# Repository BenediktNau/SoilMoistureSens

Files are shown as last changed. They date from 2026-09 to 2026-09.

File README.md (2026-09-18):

# SoilMoistureSens

Batteriebetriebener Bodenfeuchtesensor auf NodeMCU (ESP8266) mit Solarladung.
Misst alle 15 Minuten, sendet per MQTT und schläft dazwischen im Deep Sleep.
Einstellungen laufen über eine Web-Oberfläche auf dem Chip.

## Hardware

- NodeMCU (ESP-12E), versorgt über den **3V3-Pin**, VIN bleibt frei
- ADS1115 am I2C: SDA GPIO4 (D2), SCL GPIO5 (D1), ADDR an GND (Adresse 0x48),
  Sensorausgang an A0 des ADS1115. Der interne A0 des ESP bleibt frei.
- Kapazitiver Feuchtesensor v1.2 an **5 V**. Auf vielen dieser Sensoren sitzt
  ein NE555, der an 3,3 V kaum zwischen nass und trocken unterscheidet. Die
  5 V kommen aus einem MT3608-Step-up, der direkt am Akku hängt, nicht an den
  geregelten 3,3 V.
- Sensorversorgung geschaltet: GPIO14 (D5) treibt das Gate eines
  Logic-Level-N-MOSFET (z. B. 2N7000, besser IRLML2502), 10 kΩ vom Gate nach
  GND. Im Drain liegen die Masse des Sensors **und** die Masse des MT3608.
  Ein Step-up reicht auch im Ruhezustand die Eingangsspannung durch, darum
  wird er mit abgeschaltet.
- 6-V-Solarpanel 14,5 cm, davor ein Step-down auf 5,0 V (MP1584 oder
  LM2596), dann das HW-775-Lademodul (IP5306, VIN verträgt nur 4,75 bis
  5,5 V). 18650-Akku **mit Schutzschaltung** (protected, das BAT-Pad hängt
  ungeschützt an der Zelle).
- HT7333 vom BAT-Pad auf den 3V3-Pin, je 10 µF an Ein- und Ausgang. VOUT des
  HW-775 bleibt frei, der 5-V-Ausgang schaltet im Deep Sleep nach 32 s ab.
- **Brücke D0 (GPIO16) an RST**: ohne sie wacht der Chip nicht aus dem Deep Sleep auf
- Kein zusätzlicher Taster: der Reset-Taster des NodeMCU, zweimal innerhalb
  von 3 s gedrückt, öffnet den Konfigmodus
- Gehäuse unter `case/`

### Schaltplan

Rev D, Stand 2026-09-18. Quelle mit Verdrahtungstabellen und Hinweisen:
[`docs/hardware/schaltplan.html`](docs/hardware/schaltplan.html).

**Blatt 1, Versorgung**

Schaltplan Versorgung: Panel, Step-down, HW-775, 18650, HT7333, NodeMCU

**Blatt 2, Messpfad**

Schaltplan Messpfad: NodeMCU, ADS1115, MT3608, Sensor, MOSFET

Vor dem ersten Einschalten: Step-down ohne Last auf 5,0 V einstellen,
MT3608 ohne Sensor auf 5,0 V einstellen (der Trimmer reagiert oft erst nach
15 bis 25 Umdrehungen), HT7333-Ausgang auf 3,3 V prüfen. Den Sensorausgang
einmal in trockener Luft messen: der ADS1115 verträgt an 3,3 V Versorgung
höchstens 3,6 V am Eingang, typisch liefert der Sensor bis 3,0 V.

### Stückliste

| Ref | Teil | Typ / Wert | Hinweis |
|---|---|---|---|
| PV1 | Solarpanel | 6 V, 14,5 cm | Leerlauf bis 7 V |
| U2 | Step-down-Modul | MP1584EN, alternativ LM2596 | auf 5,0 V eingestellt |
| U1 | Lademodul HW-775 | IP5306 | nur VIN, GND und BAT benutzt |
| BT1 | 18650 Li-Ion mit Halter | protected, 3,0 bis 4,2 V | etwa 3 mm länger als eine nackte Zelle |
| U3 | LDO HT7333-A | 3,3 V, 250 mA | TO-92 von vorn: GND, VIN, VOUT |
| C2, C3 | Kondensator | 10 µF | C3 gern größer, bis 100 µF |
| A1 | NodeMCU | ESP-12E (ESP8266) | Versorgung über den 3V3-Pin |
| U4 | ADS1115-Modul | 16 Bit, I2C 0x48 | ADDR an GND |
| C1 | Kondensator | 100 nF | direkt am ADS1115 |
| U5 | Step-up-Modul MT3608 | auf 5,0 V eingestellt | versorgt nur den Sensor |
| J1 | Bodenfeuchtesensor | kapazitiv v1.2 | mit NE555, braucht 5 V |
| Q1 | N-MOSFET, Logic Level | 2N7000, besser IRLML2502 | schaltet Masse von U5 und J1 |
| R1 | Widerstand | 10 kΩ | Gate von Q1 nach GND |
| JP1 | Drahtbrücke | D0 nach RST | zum Flashen abziehen |

## Flashen

```bash
pio run -e esp12e -t upload
pio device monitor
```

Startet der Upload nicht, die Brücke GPIO16 zu RST für den Upload trennen.

## Bedienung

**Konfigmodus** startet beim ersten Einschalten (ohne Konfiguration) oder nach
zweimaligem Druck auf den Reset-Taster innerhalb von 3 s. Ein einzelner Druck
löst nur einen normalen Messzyklus aus.

1. Mit WLAN `SoilMoisture-Setup` verbinden, Passwort `bodenfeuchte`.
2. `http://192.168.4.1/` öffnen.
3. WLAN, MQTT-Broker, Kalibrierung und Intervall eintragen.
4. "Speichern und Messbetrieb starten".

Sobald das Heimnetz eingetragen ist, ist die Seite auch über die dort
vergebene IP erreichbar (steht im seriellen Monitor und in der WLAN-Karte).

Kalibrieren: Sensor an der Luft halten und bei "trocken" den aktuellen Wert
übernehmen, dann ins Wasserglas und bei "nass" übernehmen. Die Rohwerte des
ADS1115 liegen bei etwa 9600 bis 24000 (0,125 mV pro Schritt). Rohwert -1
heißt: der ADS1115 antwortet nicht, dann Verdrahtung und Adresse prüfen.

Statische IP: Wer eine feste Adresse einträgt, spart beim Aufwachen die
DHCP-Zeit. Gateway und Subnetzmaske sind dann Pflicht, DNS ist optional
(leer = Gateway). Feld leer lassen bedeutet DHCP.

Der Konfigmodus endet nach 5 Minuten ohne Bedienung von selbst.

**Messbetrieb**: aufwachen, Sensor und Step-up einschalten, messen, beides aus, senden,
schlafen. Ziel unter 10 Sekunden wach. Ohne WLAN oder Broker schläft der Sensor trotzdem bis zum nächsten
Intervall, damit der Akku geschont wird.

## MQTT

Topic `<Präfix>/<Gerätename>/state`, retained:

```json
{"raw":16500,"percent":52,"level":"ok","rssi":-61}
```

`level` ist `dry`, `ok` oder `wet` nach den eingestellten Schwellen.

## Entwicklung

```bash
pio test -e native      # Logik-Tests auf dem PC (braucht g++)
pio run -e esp12e       # Firmware bauen
```

Konfiguration liegt in `/config.json` im LittleFS des Chips. Zum Zurücksetzen
`pio run -e esp12e -t erase` und neu flashen.

Design-Spec: `docs/superpowers/specs/2026-09-12-config-ui-and-sleep-mode-design.md`
Schaltplan: `docs/hardware/` (HTML-Quelle und die beiden SVG-Blätter)
Mockup der Oberfläche: `docs/design/Main.dc.html`

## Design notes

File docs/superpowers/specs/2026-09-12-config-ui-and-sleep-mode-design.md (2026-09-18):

# Konfigurationsoberfläche und Messbetrieb mit Deep Sleep

Datum: 2026-09-12
Projekt: SoilMoistureSens (ESP-12E / ESP8266, PlatformIO, Arduino-Framework)

## Ziel

Der Sensor bekommt zwei Betriebsmodi:

- **Konfigmodus**: Der ESP hostet eine Web-Oberfläche, in der WLAN, MQTT,
  Kalibrierung, Bewertungsschwellen und Sendeintervall eingestellt werden
  und die aktuelle Bodenfeuchte live angezeigt wird.
- **Messbetrieb**: Der ESP wacht per Timer auf, misst, sendet per MQTT und
  geht sofort wieder in Deep Sleep. Standardintervall 15 Minuten.

WiFiManager wird entfernt. Alle Einstellungen liegen in einer eigenen
JSON-Datei im LittleFS, die WLAN-Zugangsdaten eingeschlossen.

## Nicht Teil dieses Vorhabens

- Zigbee (bräuchte andere Hardware, eigenes Projekt).
- Home-Assistant-Autodiscovery über MQTT.
- Schnellverbindung über gespeicherte BSSID/Kanal (mögliche spätere
  Akku-Optimierung). Eine statische IP ist dagegen enthalten, sie spart
  bereits die DHCP-Zeit.
- OTA-Updates.

## Hardware-Voraussetzungen

- Brücke **GPIO16 an RST** für den Timer-Wakeup aus Deep Sleep.
- **Reset-Taster** (auf dem NodeMCU vorhanden, kein zusätzlicher Taster).
  Zweimal drücken innerhalb von 3 s ist der einzige Weg in den Konfigmodus
  im laufenden Betrieb.
- Beim Flashen über USB kann die GPIO16-Brücke stören. Das steht in der
  README.
- Feuchte wird über einen **ADS1115** (I2C 0x48, Kanal A0) gemessen, nicht
  über den internen ADC. Die Sensorversorgung schaltet **GPIO14** über einen
  MOSFET; Pull-down 10 kΩ am Gate hält den Sensor im Deep Sleep aus.
- Der Sensor (v1.2 mit NE555) läuft an **5 V** aus einem MT3608-Step-up
  direkt am Akku. Der MOSFET an GPIO14 schaltet die Masse von Step-up und
  Sensor gemeinsam. Der ESP selbst hängt über einen HT7333 am Akku und wird
  am 3V3-Pin gespeist. Schaltplan Rev D unter `docs/hardware/`.

## Betriebsmodi und Startablauf

Beim Booten wird `ESP.getResetInfoPtr()->reason` ausgewertet:

| Reset-Grund | Bedeutung | Modus |
|---|---|---|
| `REASON_DEEP_SLEEP_AWAKE` | Timer-Wakeup | Messbetrieb |
| `REASON_EXT_SYS_RST`, Doppel-Reset-Markierung gesetzt | zweiter Druck auf RST innerhalb von 3 s | Konfigmodus |
| `REASON_EXT_SYS_RST`, keine Markierung | erster Druck auf RST | Markierung setzen, 3 s warten, Markierung löschen, dann wie Kaltstart |
| alle anderen (Einschalten, Software-Reset, Watchdog) | Kaltstart | Messbetrieb, falls Konfiguration gültig, sonst Konfigmodus |

Eine Konfiguration gilt als gültig, wenn SSID und MQTT-Host nicht leer sind.

Die Doppel-Reset-Markierung ist ein Magic-Wert im RTC-Nutzerspeicher
(`ESP.rtcUserMemoryRead/Write`, Block 0). Er überlebt einen Reset, nicht
aber das Stromlos-Machen; nach dem Einschalten steht dort Zufall, daher ein
32-Bit-Magic statt eines Bits. Timer-Wakeup und Kaltstart lesen die
Markierung nicht.

### Messbetrieb (Ziel: unter 10 s wach)

1. Konfiguration laden.
2. Sensor einschalten, 200 ms warten, Feuchte messen (10 Wandlungen des
   ADS1115, gemittelt), Sensor ausschalten. Antwortet der ADS1115 nicht,
   wird nichts gesendet.
3. WLAN verbinden, maximal 15 s.
4. MQTT verbinden, maximal 5 s, Nachricht veröffentlichen.
5. `ESP.deepSleep(intervalMin * 60e6)`.

Jeder Fehler (kein WLAN, kein Broker) führt trotzdem zu Schritt 5. Der Akku
wird nie durch Wiederholungsversuche belastet. Fehlerursachen gehen auf die
serielle Schnittstelle.

Während des Messbetriebs läuft kein Webserver.

### Konfigmodus

1. Konfiguration laden (Standardwerte, falls Datei fehlt).
2. Access Point `SoilMoisture-Setup` mit Passwort `bodenfeuchte` öffnen,
   IP 192.168.4.1.
3. Zusätzlich Verbindung zum gespeicherten WLAN versuchen (Modus AP+STA),
   damit die Seite auch über das Heimnetz erreichbar ist. Ein Fehlschlag
   ist kein Fehler.
4. Webserver auf Port 80 starten.
5. Schleife: HTTP bedienen, Feuchte alle 2 s messen und zwischenspeichern.

Der Konfigmodus endet

- nach **5 Minuten ohne HTTP-Anfrage** (jede Anfrage außer dem Polling von
  `/api/status` setzt den Zähler zurück, so zählt die Anzeige sichtbar
  herunter, solange niemand bedient), oder
- sofort über `POST /api/sleep` ("Speichern und Messbetrieb starten").

In beiden Fällen folgt ein regulärer Messzyklus (messen, senden, schlafen).
Die verbleibende Zeit steht im Statusendpunkt und wird oben in der Seite
angezeigt.

## Konfiguration

Datei `/config.json` im LittleFS. Struktur `Config`:

| Bereich | Feld | Typ | Standard |
|---|---|---|---|
| WLAN | `ssid` | String | leer |
| WLAN | `wifiPassword` | String | leer |
| WLAN | `staticIp` | String (IPv4) | leer = DHCP |
| WLAN | `gateway` | String (IPv4) | leer |
| WLAN | `subnet` | String (IPv4) | `255.255.255.0` |
| WLAN | `dns` | String (IPv4) | leer = Gateway |
| MQTT | `mqttHost` | String | leer |
| MQTT | `mqttPort` | uint16 | 1883 |
| MQTT | `mqttUser` | String | leer |
| MQTT | `mqttPassword` | String | leer |
| MQTT | `topicPrefix` | String | `soil` |
| MQTT | `deviceName` | String | `sensor1` |
| Kalibrierung | `dryRaw` | int | 24000 (ADS1115-Schritte, etwa 3,0 V) |
| Kalibrierung | `wetRaw` | int | 9600 (ADS1115-Schritte, etwa 1,2 V) |
| Schwellen | `dryBelowPct` | int | 30 |
| Schwellen | `wetAbovePct` | int | 70 |
| Intervall | `intervalMin` | int | 15 |

Regeln:

- Fehlende oder unlesbare Felder bekommen den Standardwert. Eine kaputte
  Datei führt zu Standardwerten, nicht zum Absturz.
- `intervalMin` wird auf 1 bis 180 begrenzt (ESP8266 schläft maximal etwa
  3 Stunden zuverlässig).
- `dryBelowPct` muss kleiner als `wetAbovePct` sein, sonst wird der
  POST mit 400 abgelehnt.
- Ist `staticIp` gesetzt, müssen `staticIp`, `gateway` und `subnet` gültige
  IPv4-Adressen sein, sonst 400. Zusätzlich muss `subnet` eine echte
  Netzmaske sein (erstes Oktett 255, Einsen zusammenhängend) und `staticIp`
  und `gateway` müssen im selben Subnetz liegen, sonst ebenfalls 400. Grund:
  Der ESP8266-Core erkennt die Argumentreihenfolge von `WiFi.config()` an
  der Maske und lehnt IP und Gateway in verschiedenen Subnetzen still ab.
  Leeres `dns` bedeutet Gateway als DNS. Leeres `staticIp` bedeutet DHCP;
  Gateway, Subnetz und DNS werden dann ignoriert.
- Schlägt `WiFi.config()` trotz Validierung fehl, meldet das Gerät seriell
  "Statische IP abgelehnt, weiter mit DHCP" und verbindet per DHCP.
- Die statische IP gilt in beiden Modi: im Messbetrieb vor `WiFi.begin`
  (spart die DHCP-Zeit), im Konfigmodus für die Heimnetz-Verbindung. Der
  Access Point behält immer 192.168.4.1.
- `WiFi.persistent(false)`: Der Arduino-Core schreibt keine eigenen
  Zugangsdaten mehr in den Flash. Einzige Quelle ist `config.json`.
- Passwörter werden beim Lesen über die API als leerer String ausgegeben und
  nur überschrieben, wenn der POST einen nicht leeren Wert liefert. Damit die
  Oberfläche anzeigen kann, ob ein Passwort hinterlegt ist, liefert die API
  zusätzlich `wifiPasswordSet` und `mqttPasswordSet` als bool.

## Web-Oberfläche

Eine einzige HTML-Seite als PROGMEM-String, kein externes CSS oder JS,
Systemschrift, Monospace für Messwerte. Layout und Farben stammen aus dem
abgenommenen Mockup (`docs/design/Main.dc.html`,
Artifact https://claude.ai/code/artifact/62b0389d-a7ac-40ed-9dd1-1d85963e8132).

Farbtoken:

| Token | Wert |
|---|---|
| Hintergrund | `#0d1116` |
| Karte | `#141a21` |
| Rahmen | `#242c36` |
| Eingabefeld | `#0a0e13` |
| Text | `#e6eaef` |
| Text gedämpft | `#8a94a1` |
| Akzent / ok | `#5eb1e8` |
| trocken | `#e8a85c` |
| nass | `#9b8cf5` |

Aufbau von oben nach unten:

1. **Kopfzeile**: Gerätename und AP-IP, rechts Pille "Konfigmodus" mit
   Restzeit mm:ss.
2. **Live-Anzeige**: Prozent groß, Bewertung als Pille, Rohwert, Balken mit
   drei Zonen und Marker. Aktualisierung alle 2 s über `/api/status`. Die
   Prozentrechnung passiert im Browser mit den aktuell eingetippten
   Kalibrier- und Schwellenwerten, so ist die Wirkung vor dem Speichern
   sichtbar.
3. **Kalibrierung**: zwei Felder mit je einem Knopf "Aktuellen Wert
   übernehmen", der den zuletzt gelesenen Rohwert einträgt.
4. **Bewertung und Intervall**: trocken unter, nass ab, Sendeintervall.
5. **WLAN**: Netzwerk als Eingabefeld mit Vorschlagsliste, Knopf "Suchen"
   ruft `/api/scan`, Passwortfeld, Anzeige der Heimnetz-IP falls verbunden.
   Darunter "Statische IP (leer = DHCP)", Gateway, Subnetzmaske und DNS.
6. **MQTT**: Broker, Port, Benutzer, Passwort, Topic-Präfix, Gerätename,
   Vorschau des Topics, Knopf "Testnachricht".
7. **Aktionen**: "Speichern" und "Speichern und Messbetrieb starten".

### HTTP-Schnittstelle

| Methode | Pfad | Zweck |
|---|---|---|
| GET | `/` | HTML-Seite |
| GET | `/api/status` | `{raw, rssi, staIp, apIp, secondsLeft}` |
| GET | `/api/config` | aktuelle Konfiguration, Passwörter leer |
| POST | `/api/config` | JSON-Body, validieren, speichern; 200 mit `ok` oder, wenn sich WLAN-Daten geändert haben, `reconnect` (die Seite wartet dann vor einem MQTT-Test auf die neue Verbindung); 400 mit Fehlertext |
| GET | `/api/scan` | `[{ssid, rssi, secure}]`, sortiert nach RSSI |
| POST | `/api/mqtt-test` | verbindet mit den **gespeicherten** MQTT-Daten und sendet eine Testnachricht; 200 oder 502 mit Fehlertext. Ohne gültigen Messwert (ADS1115 antwortet nicht) 502, es wird nichts gesendet |
| POST | `/api/sleep` | antwortet 200 und beendet den Konfigmodus |

Der Knopf "Speichern und Messbetrieb starten" ruft im Browser erst
`POST /api/config`, dann `POST /api/sleep`. Ändert ein POST die
WLAN-Einstellungen, antwortet das Gerät zuerst mit 200 und verbindet erst
etwa eine halbe Sekunde später neu, damit die Antwort über die bestehende
Verbindung noch ankommt. Leere Zahlenfelder schickt der Browser nicht mit,
der gespeicherte Wert bleibt dann erhalten. Der Knopf "Testnachricht"
speichert vorher ebenfalls, damit die Testnachricht mit den sichtbaren
Werten geht.

## MQTT-Nachricht

- Topic: `<topicPrefix>/<deviceName>/state`, retained.
- Payload: `{"raw":16500,"percent":52,"level":"ok","rssi":-61}`.
- `level` ist `dry`, `ok` oder `wet` nach den Schwellen.
- Client-ID: `<deviceName>`.
- Testnachricht: gleiches Topic, gleiche Struktur, zusätzlich `"test":true`.

## Code-Struktur

```
src/
  main.cpp            Reset-Grund auswerten, Modus wählen, Abläufe
  double_reset.h/.cpp Doppel-Reset-Markierung im RTC-Speicher
  config.h/.cpp       struct Config, Standardwerte, load()/save() über LittleFS + ArduinoJson
  moisture.h          reine Rechenlogik, ohne Arduino-Abhängigkeit
  web_ui.h/.cpp       ESP8266WebServer, Routen, PROGMEM-HTML
  mqtt_sender.h/.cpp  verbinden, publizieren, Timeout
  mqtt_payload.h      Topic und Payload als Strings, reine Logik
  boot_mode.h         Modus aus Reset-Grund, reine Logik
  ipv4.h              IPv4-Parser, reine Logik
  wifi_station.h/.cpp beginStation(cfg): statische IP anwenden, WiFi.begin
  index_html.h        die HTML-Seite als Raw-String-Literal in PROGMEM
test/
  test_moisture/      Unit-Tests der Rechenlogik (native)
  test_config/        Unit-Tests der JSON-Konvertierung (native)
```

### moisture.h (reine Logik)

```cpp
int moisturePercent(int raw, int dryRaw, int wetRaw);     // 0..100, dry/wet beliebig geordnet
enum class Level { Dry, Ok, Wet };
Level classify(int percent, int dryBelow, int wetAbove);
const char* levelName(Level);                             // "dry" / "ok" / "wet"
```

Ohne `Arduino.h`, damit die Tests auf dem PC laufen. Sonderfall
`dryRaw == wetRaw` liefert 0 statt Division durch Null.

### config.h

```cpp
struct Config { ... Felder wie oben ... };
Config defaultConfig();
bool configIsValid(const Config&);
bool parseConfig(const char* json, Config& io);    // fehlende Felder bleiben wie in io
const char* validateConfig(const Config&);         // nullptr oder Fehlertext
size_t serializeConfig(const Config&, char* buf, size_t n, bool maskSecrets);
bool loadConfig(Config&);                          // LittleFS, nur auf Gerät
bool saveConfig(const Config&);

// ipv4.h, reine Logik
bool parseIpv4(const char* s, uint8_t out[4]);     // "192.168.1.5" -> Bytes
```

`parseConfig` und `serializeConfig` hängen nur von ArduinoJson ab und sind
native testbar. `loadConfig`/`saveConfig` sind dünne Hüllen um LittleFS.

### Bibliotheken

`platformio.ini`:

```ini
[env:esp12e]
platform = espressif8266
board = esp12e
framework = arduino
board_build.f_cpu = 160000000L
board_build.filesystem = littlefs
monitor_speed = 115200
lib_deps =
  bblanchon/ArduinoJson@^7
  knolleary/PubSubClient@^2.8

[env:native]
platform = native
lib_deps = bblanchon/ArduinoJson@^7
build_flags = -std=c++17
test_build_src = no
```

WiFiManager entfällt.

## Fehlerbehandlung

| Situation | Verhalten |
|---|---|
| `config.json` fehlt oder ist kaputt | Standardwerte, Konfigmodus |
| WLAN im Messbetrieb nicht erreichbar | nach 15 s schlafen, seriell melden |
| Broker nicht erreichbar | nach 5 s schlafen, seriell melden |
| Ungültiger POST (Schwellen, ungültige IP) | 400 mit Klartext-Fehler, nichts gespeichert |
| LittleFS-Schreibfehler | 500, alte Datei bleibt (Schreiben über `/config.json.tmp`, dann `rename`, das die alte Datei atomar ersetzt; kein `remove` davor) |
| Reset-Taster einmal während Messbetrieb | Reset, 3 s Wartefenster, dann normaler Messzyklus |
| Reset-Taster zweimal innerhalb von 3 s | Konfigmodus |

## Tests

- **Native Unit-Tests** (`pio test -e native`): `moisturePercent`,
  `classify`, Grenzfälle (Klemmen auf 0..100, vertauschte Kalibrierwerte,
  gleiche Kalibrierwerte), `parseConfig` mit vollständigem, leerem und
  teilweisem JSON, `serializeConfig` mit und ohne Maskierung, Round-Trip,
  `validateConfig` für Schwellen und statische IP, `parseIpv4`,
  `chooseBootMode`, MQTT-Topic und -Payload.
- **Gerätetests von Hand** mit seriellem Monitor: Reset-Grund-Erkennung
  (einfacher Reset, Doppel-Reset, Timer, Einschalten), Konfigmodus-Timeout, Seite über AP und
  Heimnetz, Scan, Speichern, Testnachricht am Broker sichtbar,
  Messzyklus-Dauer, Deep Sleep und Wakeup.

## Offene Punkte

Keine. Spätere Erweiterungen (Autodiscovery, Schnellverbindung, OTA) sind
oben unter "Nicht Teil dieses Vorhabens" festgehalten.

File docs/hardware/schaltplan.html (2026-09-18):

Schaltplan · Rev D · Versorgung und Messpfad

# SoilMoistureSens

Blatt 1 zeigt den Strompfad vom Solarpanel über Step-down, HW-775 und Akku bis zum 3,3-V-Regler am NodeMCU. Blatt 2 ist der Messpfad mit ADS1115 und Sensor. Neu in Rev D: der Sensor läuft an 5 V aus einem MT3608-Step-up, der direkt am Akku hängt und nur für die Messung eingeschaltet wird. Konfigmodus: zweimal RST innerhalb von 3 s.

Stand 2026-09-18 Panel 6 V · 14,5 cm Lader HW-775 (IP5306) Eingang Step-down 5 V Akku 18650 protected Regler HT7333 → 3V3-Pin Sensor 5 V über MT3608 Board NodeMCU

Blatt 1 · Versorgung

Das HW-775 ist ein Powerbank-Modul: sein 5-V-Ausgang VOUT schaltet bei kleiner Last nach 32 s ab und bleibt deshalb frei. Der ESP hängt über den HT7333 direkt am BAT-Pad. Der Step-down davor hält den Eingang unter 5,5 V, denn das 6-V-Panel liefert im Leerlauf rund 7 V. Tiefentlade- und Kurzschlussschutz sitzen in der Zelle, darum muss es eine Protected-Zelle sein. Der ESP hängt am selben Knoten wie der Lader (VBAT), aber hinter dem HT7333, damit er bei 3,0 bis 4,2 V Akkuspannung stabil 3,3 V bekommt. VIN bleibt frei, der Regler auf dem NodeMCU wäre bei Akkuspannung schon im Dropout. Am Knoten VBAT hängt außerdem der Step-up für den Sensor, siehe Blatt 2.

Blatt 2 · Messpfad

Der v1.2-Sensor mit NE555 misst an 3,3 V unbrauchbar, darum bekommt er 5 V aus dem MT3608. Der Step-up hängt direkt an VBAT, nicht an den geregelten 3,3 V: so belasten sein Einschaltstrom und sein Schaltrippel weder den knappen HT7333 noch die Versorgung des ADS1115. Farbig ist die geschaltete Masse. Q1 trennt Step-up und Sensor gemeinsam, denn ein Step-up reicht auch im Ruhezustand die Eingangsspannung zum Ausgang durch und würde sonst dauernd Strom ziehen.

## Verdrahtung Blatt 1

Von | Nach | Hinweis
Panel + | U2 IN+ | Polung vorher mit Multimeter prüfen, Panel in die Sonne halten
Panel − | U2 IN−
U2 OUT+ | HW-775 VIN | U2 vorher ohne Last auf 5,0 V einstellen und nachmessen
U2 OUT− | HW-775 GND (neben VIN) | alle GND-Pads des HW-775 sind verbunden
HW-775 BAT | 18650 + | Knoten VBAT, hier zweigen HT7333 und MT3608 ab
HW-775 GND (neben BAT) | 18650 − | Knoten GND
HW-775 VOUT, KEY | frei | 5-V-Ausgang schaltet im Deep Sleep ab
VBAT | HT7333 IN · C2 | C2 10 µF dicht am Regler
VBAT | MT3608 IN+ (Blatt 2) | direkt vom Akku, nicht von den 3,3 V
HT7333 OUT | NodeMCU 3V3 · C3 | C3 10 µF, dann 3V3-Pin. Nicht VIN
HT7333 GND | NodeMCU GND | gemeinsame Masse mit BAT−
NodeMCU D0 | NodeMCU RST | Brücke, zum Flashen trennen
NodeMCU VIN, 5V | frei

## Verdrahtung Blatt 2

Von | Nach | Hinweis
NodeMCU 3V3 | ADS VDD | C1 100 nF direkt an VDD/GND des ADS1115
VBAT (Blatt 1) | MT3608 IN+ | Ausgang vorher ohne Sensor auf 5,0 V einstellen
MT3608 OUT+ | Sensor VCC | 5 V nur während der Messung
NodeMCU GND | ADS GND · ADS ADDR | ADDR auf GND ergibt Adresse 0x48
NodeMCU D1 | ADS SCL | GPIO5
NodeMCU D2 | ADS SDA | GPIO4
ADS A0 | Sensor AOUT | 1,2 bis 3 V. In trockener Luft nachmessen, der ADS1115 verträgt maximal 3,6 V
NodeMCU D5 | Q1 Gate · R1 | R1 10 kΩ nach GND hält Q1 im Deep Sleep gesperrt
Sensor GND · MT3608 IN−/OUT− | Q1 Drain | Q1 Source an GND. Beide Massen gemeinsam geschaltet

## Hinweise

- Sensor braucht 5 V. Auf vielen v1.2-Sensoren sitzt ein NE555, der erst ab 4,5 V sauber schwingt. An 3,3 V unterscheiden sich nass und trocken kaum. Der MT3608 macht aus der Akkuspannung 5,0 V, nur solange D5 auf HIGH liegt.
  Boards mit TLC555 laufen auch an 3,3 V. Dann kann U5 entfallen und Sensor-VCC an den 3V3-Pin.
- MT3608 vor dem Anschließen einstellen. Neue Module stehen oft auf über 20 V oder reagieren erst nach 15 bis 25 Umdrehungen des Trimmers. Ohne Sensor an den Akku, Masse direkt an GND, auf 5,0 V drehen, erst dann über Q1 einschleifen.
  AOUT danach einmal in trockener Luft messen. Bleibt er unter 3,5 V, passt es ohne Teiler. Ein 10-kΩ-Widerstand in der AOUT-Leitung ist optional und begrenzt den Strom in den ADS1115, wenn die abgeschaltete Sensormasse nach oben driftet.
- 3V3-Pin statt VIN. Der AMS1117 auf dem NodeMCU braucht rund 1 V mehr am Eingang als er ausgibt. Bei 3,7 V Akku kämen unter 3 V heraus, der ESP würde beim WLAN-Senden abstürzen. Der HT7333 kommt mit 0,1 V Abstand aus und liefert bis 3,4 V Akku volle 3,3 V.
  Der AMS1117 hängt dann mit seinem Ausgang parallel am 3V3-Netz, ohne Eingang. Das ist unkritisch und gängige Praxis.
- VOUT nicht benutzen. Der IP5306 schaltet seinen 5-V-Ausgang ab, sobald 32 s lang weniger als 45 mA fließen. Im Deep Sleep wäre der ESP nach einer halben Minute stromlos und käme nie wieder hoch. Darum hängt der HT7333 direkt am BAT-Pad, KEY bleibt frei.
  Der IP5306 selbst zieht im Standby rund 50 µA aus der Zelle. Die LEDs leuchten nur beim Laden.
- Eingang maximal 5,5 V. Der IP5306 ist für 4,75 bis 5,5 V am VIN gebaut, nicht für ein 6-V-Panel. Sobald die Zelle voll ist und der Lader abschaltet, steht das Panel im Leerlauf mit rund 7 V am Eingang. Der MP1584-Step-down auf 5,0 V verhindert das.
  Alternative ohne U2: ein 5-V-Panel direkt an VIN. Oder das HW-775 durch ein TP4056-Modul mit Schutz ersetzen, das verträgt 6-V-Panels direkt und passt in denselben Rahmen im Gehäuse.
- Laden in Schüben ist normal. Der Lader hat kein MPPT. Bei schwachem Licht bricht die Panelspannung unter Last ein, der IP5306 stoppt unter 4,75 V, das Panel erholt sich, es geht wieder los. Unterm Strich kommt trotzdem Ladung an.
- Protected-Zelle ist Pflicht. Der Tiefentladeschutz des IP5306 wirkt nur auf VOUT, das BAT-Pad hängt direkt an der Zelle. Tiefentladung, Kurzschluss und ein defekter Lader werden allein vom Schutz-IC in der Zelle abgefangen.
  Hat der Schutz einmal wegen Tiefentladung ausgelöst, liefert die Zelle 0 V, bis Ladespannung anliegt. Kurz Panel in die Sonne oder USB ans HW-775, dann schaltet sie wieder durch. Die Zelle ist etwa 3 mm länger als eine nackte, das muss in den Halter passen.
- Q1 trägt jetzt auch den Step-up. Beim Einschalten lädt der MT3608 kurz seine Kondensatoren. Ein 2N7000 reicht dafür, ein IRLML2502 oder AO3400 hat bei 3,3 V Gatespannung deutlich weniger Widerstand und ist die bessere Wahl, falls die ersten Messwerte nach dem Einschalten abweichen.
- Flashen. Brücke D0–RST abziehen, sonst startet der Upload oft nicht. USB am NodeMCU und Akku gleichzeitig ist elektrisch unkritisch (beide Regler liefern 3,3 V), sauberer ist es, die Zelle zum Flashen abzuklemmen.
- Ruhestrom hängt vom Board ab. Ein Amica-NodeMCU (schmal, CP2102) speist den USB-Chip nur aus dem USB-Anschluss. Beim LoLin V3 (breit, CH340) hängt der CH340 am 3V3-Netz und kostet im Deep Sleep Ruhestrom. Am besten einmal im Schlaf messen.
- Konfigmodus ohne extra Taster. RST einmal drücken: der ESP wartet 3 s und misst dann normal. Innerhalb der 3 s nochmal drücken: Konfigmodus. Der Merker liegt im RTC-Speicher und überlebt den Reset, aber kein Stromlos-Machen.

## Stückliste

Ref | Teil | Typ / Wert | Hinweis
PV1 | Solarpanel | 6 V, 14,5 cm | Leerlauf bis 7 V
U2 | Step-down-Modul | MP1584EN, alternativ LM2596 | auf 5,0 V eingestellt
U1 | Lademodul HW-775 | IP5306 | nur VIN, GND und BAT benutzt
BT1 | 18650 Li-Ion mit Halter | protected, 3,0 bis 4,2 V | etwa 3 mm länger als eine nackte Zelle
U3 | LDO HT7333-A | 3,3 V, 250 mA | TO-92: GND, VIN, VOUT von links, flache Seite vorn
C2, C3 | Kondensator | 10 µF | C3 gern größer, bis 100 µF
A1 | NodeMCU | ESP-12E (ESP8266) | Versorgung über den 3V3-Pin
U4 | ADS1115-Modul | 16 Bit, I2C 0x48 | ADDR an GND
C1 | Kondensator | 100 nF | direkt am ADS1115
U5 | Step-up-Modul MT3608 | auf 5,0 V eingestellt | versorgt nur den Sensor
J1 | Bodenfeuchtesensor | kapazitiv v1.2 | mit NE555, braucht 5 V
Q1 | N-MOSFET, Logic Level | 2N7000, besser IRLML2502 | schaltet Masse von U5 und J1
R1 | Widerstand | 10 kΩ | Gate von Q1 nach GND
JP1 | Drahtbrücke | D0 nach RST | zum Flashen abziehen

## Firmware

Messpfad in src/moisture_sensor.cpp mit der Bibliothek ADS1X15 von Rob Tillaart: Sensor und Step-up über D5 ein, 200 ms warten, zehn Wandlungen mitteln, wieder aus. Doppel-Reset in src/double_reset.cpp: Magic-Wert im RTC-Nutzerspeicher, 3 s Fenster, Auswertung in chooseBootMode.

ADS1115: Adresse 0x48, Kanal A0, GAIN 1 (±4,096 V), Single-Shot, 128 SPS. Antwortet er nicht, liefert das Modul den Rohwert -1 und der Messbetrieb schläft ohne zu senden weiter. Timer-Wakeup und Einschalten lesen den Doppel-Reset-Merker nicht.

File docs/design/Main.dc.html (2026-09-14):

Bodenfeuchte

sensor1 · 192.168.4.1

Konfigmodus 4:32

Aktuelle Feuchte

{{m.pct}} %

{{m.label}} Roh {{m.raw}}

030 trocken70 nass100

Aktualisiert alle 2 Sekunden. Prozent rechnet mit den unten eingetragenen Kalibrierwerten.

Kalibrierung

Rohwert trocken (Sensor an der Luft)

226

Aktuellen Wert übernehmen

Rohwert nass (Sensor im Wasser)

181

Aktuellen Wert übernehmen

Sensor in Luft halten, Wert übernehmen. Dann in ein Wasserglas, Wert übernehmen.

Bewertung und Intervall

Trocken unter

30%

Nass ab

70%

Sendeintervall

15Minuten

Zwischen zwei Messungen schläft der Sensor. Kürzere Intervalle kosten Akku.

WLAN

verbunden · 192.168.1.42

Netzwerk

Gartenhaus

Suchen

Passwort

•••••••• (unverändert)

Statische IP

leer = DHCP

Gateway

192.168.1.1

Subnetzmaske

255.255.255.0

DNS

leer = Gateway

Eine feste IP spart beim Aufwachen die DHCP-Zeit und damit Akku. Gateway und Maske sind dann Pflicht.

MQTT

Broker

192.168.1.10

Port

1883

Benutzer

optional

Passwort

optional

Topic-Präfix

soil

Gerätename

sensor1

Sendet nach soil/sensor1/state

Testnachricht

Speichern

Speichern und Messbetrieb starten

Danach misst der Sensor, sendet und schläft 15 Minuten. Zurück ins Menü: Taster am Gehäuse drücken.

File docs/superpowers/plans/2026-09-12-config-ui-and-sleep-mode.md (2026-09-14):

# Konfigurationsoberfläche und Messbetrieb mit Deep Sleep – Implementierungsplan

> **For agentic workers:** REQUIRED SUB-SKILL: Use superpowers:subagent-driven-development (recommended) or superpowers:executing-plans to implement this plan task-by-task. Steps use checkbox (`- [ ]`) syntax for tracking.

**Goal:** Der ESP-12E-Bodenfeuchtesensor bekommt eine Web-Oberfläche zum Einstellen von WLAN, MQTT, Kalibrierung, Schwellen und Intervall sowie einen Messbetrieb, der per Timer aufwacht, misst, per MQTT sendet und wieder in Deep Sleep geht.

**Architecture:** Beim Booten entscheidet der Reset-Grund über den Modus (Timer-Wakeup = Messbetrieb, Reset-Taster = Konfigmodus). Alle Einstellungen liegen in `/config.json` im LittleFS. Reine Logik (Prozentrechnung, Bewertung, JSON-Konvertierung, Modusauswahl, MQTT-Payload) ist Arduino-frei in Headern und wird nativ auf dem PC getestet. Gerätecode (Webserver, LittleFS, MQTT, WLAN, Deep Sleep) wird per Build und seriellem Monitor am Gerät geprüft.

**Tech Stack:** PlatformIO, Arduino-Core ESP8266, ESP8266WebServer, LittleFS, ArduinoJson 7, PubSubClient 2.8, Unity (PlatformIO-Tests, Umgebung `native`).

**Spec:** `docs/superpowers/specs/2026-09-12-config-ui-and-sleep-mode-design.md`

## Global Constraints

- Board `esp12e`, Framework `arduino`, `board_build.f_cpu = 160000000L`, `monitor_speed = 115200`.
- Bibliotheken auf dem Gerät: `bblanchon/ArduinoJson@^7`, `knolleary/PubSubClient@^2.8`. WiFiManager wird am Ende entfernt (Task 7), vorher bleibt es, damit jeder Zwischenstand baut.
- Access Point: Name `SoilMoisture-Setup`, Passwort `bodenfeuchte`.
- Konfigdatei: `/config.json` im LittleFS. Standardwerte: `mqttPort` 1883, `topicPrefix` `soil`, `deviceName` `sensor1`, `dryRaw` 226, `wetRaw` 181, `dryBelowPct` 30, `wetAbovePct` 70, `intervalMin` 15. Alle Strings leer.
- `intervalMin` wird auf 1..180 begrenzt, `dryBelowPct`/`wetAbovePct` auf 0..100. `dryBelowPct < wetAbovePct` ist Pflicht, sonst 400.
- Passwörter werden über die API leer ausgegeben und nur bei nicht leerem Wert überschrieben. Zusätzlich liefert die API `wifiPasswordSet` und `mqttPasswordSet` als bool.
- Statische IP: Felder `staticIp`, `gateway`, `subnet` (Standard `255.255.255.0`), `dns`, alle IPv4-Strings. Leeres `staticIp` = DHCP, die anderen drei werden dann ignoriert. Ist `staticIp` gesetzt, müssen `staticIp`, `gateway`, `subnet` gültige IPv4-Adressen sein, sonst 400. Leeres `dns` = Gateway. Gilt in beiden Modi vor `WiFi.begin`; der Access Point bleibt 192.168.4.1.
- Konfiguration ist gültig, wenn `ssid` und `mqttHost` nicht leer sind.
- Zeiten: WLAN maximal 15 s, MQTT-Socket maximal 5 s, Konfigmodus 5 Minuten ohne Anfrage (Anfragen an `/api/status` zählen nicht).
- MQTT-Topic `<topicPrefix>/<deviceName>/state`, retained, Payload `{"raw":N,"percent":N,"level":"dry|ok|wet","rssi":N}`, Testnachricht zusätzlich `,"test":true`. Client-ID = `deviceName`.
- Farbtoken der Oberfläche: Hintergrund `#0d1116`, Karte `#141a21`, Rahmen `#242c36`, Eingabefeld `#0a0e13`, Text `#e6eaef`, gedämpft `#8a94a1`, Akzent/ok `#5eb1e8`, trocken `#e8a85c`, nass `#9b8cf5`.
- Serielle Meldungen und Kommentare auf Deutsch, Bezeichner auf Englisch (wie bisher in `src/main.cpp`).
- Keine externen Ressourcen in der HTML-Seite (kein CDN, kein Webfont).

---

## Dateistruktur

| Datei | Zuständigkeit | Task |
|---|---|---|
| `platformio.ini` | Umgebungen `esp12e` und `native`, Bibliotheken | 1, 7 |
| `src/moisture.h` | Prozent aus Rohwert, Bewertung, `Reading`; header-only, Arduino-frei | 1 |
| `src/boot_mode.h` | Modus aus Reset-Grund; header-only | 2 |
| `src/ipv4.h` | IPv4-String prüfen und in Bytes wandeln; header-only | 3 |
| `src/config.h` / `src/config.cpp` | `Config`, Standardwerte, Gültigkeit, JSON parse/serialize, LittleFS load/save | 3, 5 |
| `src/wifi_station.h` / `.cpp` | `beginStation(cfg)`: statische IP anwenden, `WiFi.begin` (Gerät) | 5 |
| `src/mqtt_payload.h` | Topic und Payload als Strings; header-only | 4 |
| `src/mqtt_sender.h` / `.cpp` | MQTT verbinden und veröffentlichen (Gerät) | 5 |
| `src/index_html.h` | HTML-Seite als PROGMEM-String | 6 |
| `src/web_ui.h` / `.cpp` | Webserver, Routen, Timeout, Sleep-Anforderung | 6 |
| `src/main.cpp` | Startablauf, Messzyklus, Konfigmodus, Deep Sleep | 7 |
| `test/test_moisture/test_main.cpp` | Tests Prozent und Bewertung | 1 |
| `test/test_boot_mode/test_main.cpp` | Tests Modusauswahl | 2 |
| `test/test_ipv4/test_main.cpp` | Tests IPv4-Parser | 3 |
| `test/test_config/test_main.cpp` | Tests JSON parse/serialize, Validierung | 3 |
| `test/test_mqtt_payload/test_main.cpp` | Tests Topic und Payload | 4 |
| `README.md` | Hardware, Flashen, Bedienung | 8 |

---

### Task 0: Git-Repository und Compiler für native Tests

**Files:**
- Create: `.git/` (per `git init`)
- Modify: `.gitignore`

**Interfaces:**
- Produces: ein Repository für die Commits der folgenden Tasks; `g++` für `pio test -e native`.

- [ ] **Step 1: gcc-c++ installieren (Fedora)**

Braucht Root. Der Nutzer tippt im Prompt:

```
! sudo dnf install -y gcc-c++
```

Prüfen:

```bash
g++ --version | head -1
```

Erwartet: eine Zeile mit `g++ (GCC) ...`.

- [ ] **Step 2: .gitignore ergänzen**

Aktueller Inhalt bleibt, dazu am Ende:

```
docs/design/bodenfeuchte-konfigseite.html
```

Grund: Das ist die zusammengesetzte Canvas-Datei mit eingebettetem Editor (mehrere MB). Die Quelldateien `Main.dc.html` und `canvas.json` bleiben versioniert.

- [ ] **Step 3: Repository anlegen und Ausgangsstand committen**

```bash
cd /home/bnau/workspace/SoilMoistureSens
git init -b main
git add .
git commit -m "chore: Ausgangsstand mit WiFiManager-Setup, Gehäuse und Design-Spec"
```

Erwartet: `git log --oneline` zeigt einen Commit. `git status` ist sauber.

---

### Task 1: Native Testumgebung und Feuchte-Logik

**Files:**
- Modify: `platformio.ini`
- Create: `src/moisture.h`
- Create: `test/test_moisture/test_main.cpp`

**Interfaces:**
- Produces:
  ```cpp
  enum class Level { Dry, Ok, Wet };
  int moisturePercent(int raw, int dryRaw, int wetRaw);            // 0..100
  Level classify(int percent, int dryBelowPct, int wetAbovePct);
  const char* levelName(Level level);                              // "dry" | "ok" | "wet"
  const char* levelNameDe(Level level);                            // "trocken" | "ok" | "nass"
  ```
  `Reading` und `evaluateReading` kommen in Task 3 dazu, sobald `Config` existiert.

- [ ] **Step 1: platformio.ini um native-Umgebung und Bibliotheken erweitern**

Datei komplett ersetzen:

```ini
[env:esp12e]
platform = espressif8266
board = esp12e
framework = arduino
board_build.f_cpu = 160000000L
board_build.filesystem = littlefs
monitor_speed = 115200
lib_deps =
  tzapu/WiFiManager
  bblanchon/ArduinoJson@^7
  knolleary/PubSubClient@^2.8

[env:native]
platform = native
lib_deps = bblanchon/ArduinoJson@^7
build_flags = -std=c++17 -Isrc
test_build_src = yes
build_src_filter = -<*> +<config.cpp>
```

Hinweis: `build_src_filter` sorgt dafür, dass nativ nur `config.cpp` (ab Task 3) mitkompiliert wird, nicht der Gerätecode. Bis Task 3 existiert die Datei nicht, das ist für den Filter kein Fehler.

- [ ] **Step 2: Fehlschlagenden Test schreiben**

`test/test_moisture/test_main.cpp`:

```cpp
#include <unity.h>
#include "moisture.h"

void setUp() {}
void tearDown() {}

void test_percent_at_dry_is_zero() {
  TEST_ASSERT_EQUAL_INT(0, moisturePercent(226, 226, 181));
}

void test_percent_at_wet_is_hundred() {
  TEST_ASSERT_EQUAL_INT(100, moisturePercent(181, 226, 181));
}

void test_percent_in_between() {
  // Mitte zwischen 226 und 181 ist 203.5, Ganzzahl-Rundung liefert 51
  TEST_ASSERT_EQUAL_INT(51, moisturePercent(203, 226, 181));
}

void test_percent_is_clamped_below() {
  TEST_ASSERT_EQUAL_INT(0, moisturePercent(300, 226, 181));
}

void test_percent_is_clamped_above() {
  TEST_ASSERT_EQUAL_INT(100, moisturePercent(100, 226, 181));
}

void test_percent_with_swapped_calibration() {
  // Sensor, bei dem nass den hoeheren Rohwert hat
  TEST_ASSERT_EQUAL_INT(0, moisturePercent(100, 100, 900));
  TEST_ASSERT_EQUAL_INT(100, moisturePercent(900, 100, 900));
  TEST_ASSERT_EQUAL_INT(50, moisturePercent(500, 100, 900));
}

void test_percent_with_equal_calibration_is_zero() {
  TEST_ASSERT_EQUAL_INT(0, moisturePercent(200, 200, 200));
}

void test_classify_dry_ok_wet() {
  TEST_ASSERT_EQUAL(Level::Dry, classify(0, 30, 70));
  TEST_ASSERT_EQUAL(Level::Dry, classify(29, 30, 70));
  TEST_ASSERT_EQUAL(Level::Ok, classify(30, 30, 70));
  TEST_ASSERT_EQUAL(Level::Ok, classify(69, 30, 70));
  TEST_ASSERT_EQUAL(Level::Wet, classify(70, 30, 70));
  TEST_ASSERT_EQUAL(Level::Wet, classify(100, 30, 70));
}

void test_level_names() {
  TEST_ASSERT_EQUAL_STRING("dry", levelName(Level::Dry));
  TEST_ASSERT_EQUAL_STRING("ok", levelName(Level::Ok));
  TEST_ASSERT_EQUAL_STRING("wet", levelName(Level::Wet));
  TEST_ASSERT_EQUAL_STRING("trocken", levelNameDe(Level::Dry));
  TEST_ASSERT_EQUAL_STRING("nass", levelNameDe(Level::Wet));
}

int main(int, char**) {
  UNITY_BEGIN();
  RUN_TEST(test_percent_at_dry_is_zero);
  RUN_TEST(test_percent_at_wet_is_hundred);
  RUN_TEST(test_percent_in_between);
  RUN_TEST(test_percent_is_clamped_below);
  RUN_TEST(test_percent_is_clamped_above);
  RUN_TEST(test_percent_with_swapped_calibration);
  RUN_TEST(test_percent_with_equal_calibration_is_zero);
  RUN_TEST(test_classify_dry_ok_wet);
  RUN_TEST(test_level_names);
  return UNITY_END();
}
```

- [ ] **Step 3: Test laufen lassen, Fehlschlag prüfen**

```bash
pio test -e native -f test_moisture
```

Erwartet: Build-Fehler `moisture.h: No such file or directory`.

- [ ] **Step 4: moisture.h schreiben**

`src/moisture.h`:

```cpp
#pragma once

// Reine Rechenlogik ohne Arduino-Abhaengigkeit, damit sie nativ testbar ist.

enum class Level { Dry, Ok, Wet };

// Prozent 0..100 aus einem Rohwert. dryRaw und wetRaw duerfen in beliebiger
// Reihenfolge liegen. Gleiche Kalibrierwerte liefern 0 statt Division durch Null.
inline int moisturePercent(int raw, int dryRaw, int wetRaw) {
  long span = (long)wetRaw - (long)dryRaw;
  if (span == 0) return 0;
  long pct = ((long)raw - (long)dryRaw) * 100L / span;
  if (pct < 0) return 0;
  if (pct > 100) return 100;
  return (int)pct;
}

inline Level classify(int percent, int dryBelowPct, int wetAbovePct) {
  if (percent < dryBelowPct) return Level::Dry;
  if (percent >= wetAbovePct) return Level::Wet;
  return Level::Ok;
}

inline const char* levelName(Level level) {
  switch (level) {
    case Level::Dry: return "dry";
    case Level::Wet: return "wet";
    default:         return "ok";
  }
}

inline const char* levelNameDe(Level level) {
  switch (level) {
    case Level::Dry: return "trocken";
    case Level::Wet: return "nass";
    default:         return "ok";
  }
}
```

- [ ] **Step 5: Test laufen lassen, Erfolg prüfen**

```bash
pio test -e native -f test_moisture
```

Erwartet: `9 Tests 0 Failures 0 Ignored` und `PASSED`.

Hinweis zur Rundung: `(203 - 226) * 100 / (181 - 226)` = `-2300 / -45` = 51 (Ganzzahl). Falls der Test 51 nicht trifft, stimmt die Formel nicht, nicht der Test.

- [ ] **Step 6: Gerätebuild prüfen (bestehendes main.cpp muss weiter bauen)**

```bash
pio run -e esp12e
```

Erwartet: `SUCCESS`. Die neuen Bibliotheken werden dabei geladen.

- [ ] **Step 7: Commit**

```bash
git add platformio.ini src/moisture.h test/test_moisture/test_main.cpp
git commit -m "feat: Feuchte-Logik als nativ testbarer Header, native Testumgebung"
```

---

### Task 2: Modusauswahl aus dem Reset-Grund

**Files:**
- Create: `src/boot_mode.h`
- Create: `test/test_boot_mode/test_main.cpp`

**Interfaces:**
- Produces:
  ```cpp
  enum class BootMode { Measure, Configure };
  // Werte entsprechen rst_reason aus user_interface.h des ESP8266-SDK
  constexpr uint32_t RST_REASON_DEEP_SLEEP_AWAKE = 5;
  constexpr uint32_t RST_REASON_EXT_SYS = 6;
  BootMode chooseBootMode(uint32_t resetReason, bool configValid);
  const char* bootModeName(BootMode m);   // "Messbetrieb" | "Konfigmodus"
  ```

- [ ] **Step 1: Fehlschlagenden Test schreiben**

`test/test_boot_mode/test_main.cpp`:

```cpp
#include <unity.h>
#include "boot_mode.h"

void setUp() {}
void tearDown() {}

void test_timer_wakeup_measures_even_without_valid_config() {
  TEST_ASSERT_EQUAL(BootMode::Measure, chooseBootMode(RST_REASON_DEEP_SLEEP_AWAKE, true));
  TEST_ASSERT_EQUAL(BootMode::Measure, chooseBootMode(RST_REASON_DEEP_SLEEP_AWAKE, false));
}

void test_reset_button_configures() {
  TEST_ASSERT_EQUAL(BootMode::Configure, chooseBootMode(RST_REASON_EXT_SYS, true));
  TEST_ASSERT_EQUAL(BootMode::Configure, chooseBootMode(RST_REASON_EXT_SYS, false));
}

void test_cold_boot_depends_on_config() {
  const uint32_t powerOn = 0, softRestart = 4, watchdog = 1;
  TEST_ASSERT_EQUAL(BootMode::Measure, chooseBootMode(powerOn, true));
  TEST_ASSERT_EQUAL(BootMode::Configure, chooseBootMode(powerOn, false));
  TEST_ASSERT_EQUAL(BootMode::Measure, chooseBootMode(softRestart, true));
  TEST_ASSERT_EQUAL(BootMode::Configure, chooseBootMode(watchdog, false));
}

void test_names() {
  TEST_ASSERT_EQUAL_STRING("Messbetrieb", bootModeName(BootMode::Measure));
  TEST_ASSERT_EQUAL_STRING("Konfigmodus", bootModeName(BootMode::Configure));
}

int main(int, char**) {
  UNITY_BEGIN();
  RUN_TEST(test_timer_wakeup_measures_even_without_valid_config);
  RUN_TEST(test_reset_button_configures);
  RUN_TEST(test_cold_boot_depends_on_config);
  RUN_TEST(test_names);
  return UNITY_END();
}
```

- [ ] **Step 2: Test laufen lassen, Fehlschlag prüfen**

```bash
pio test -e native -f test_boot_mode
```

Erwartet: Build-Fehler `boot_mode.h: No such file or directory`.

- [ ] **Step 3: boot_mode.h schreiben**

`src/boot_mode.h`:

```cpp
#pragma once
#include <stdint.h>

// Entscheidet anhand des Reset-Grunds, ob gemessen oder konfiguriert wird.
// Timer-Wakeup aus Deep Sleep: messen. Reset-Taster: Konfigmodus.
// Alles andere (Einschalten, Software-Reset, Watchdog): messen, wenn eine
// gueltige Konfiguration vorliegt, sonst Konfigmodus.

enum class BootMode { Measure, Configure };

// Werte aus rst_reason (user_interface.h des ESP8266 Non-OS SDK)
constexpr uint32_t RST_REASON_DEEP_SLEEP_AWAKE = 5;
constexpr uint32_t RST_REASON_EXT_SYS = 6;

inline BootMode chooseBootMode(uint32_t resetReason, bool configValid) {
  if (resetReason == RST_REASON_DEEP_SLEEP_AWAKE) return BootMode::Measure;
  if (resetReason == RST_REASON_EXT_SYS) return BootMode::Configure;
  return configValid ? BootMode::Measure : BootMode::Configure;
}

inline const char* bootModeName(BootMode m) {
  return m == BootMode::Measure ? "Messbetrieb" : "Konfigmodus";
}
```

- [ ] **Step 4: Test laufen lassen, Erfolg prüfen**

```bash
pio test -e native -f test_boot_mode
```

Erwartet: `4 Tests 0 Failures`.

- [ ] **Step 5: Commit**

```bash
git add src/boot_mode.h test/test_boot_mode/test_main.cpp
git commit -m "feat: Modusauswahl aus Reset-Grund"
```

---

### Task 3: Konfigurationsstruktur, IPv4-Parser und JSON-Konvertierung

**Files:**
- Create: `src/ipv4.h`
- Create: `test/test_ipv4/test_main.cpp`
- Create: `src/config.h`
- Create: `src/config.cpp` (nur der Arduino-freie Teil; LittleFS kommt in Task 5)
- Modify: `src/moisture.h` (Reading und evaluateReading ergänzen)
- Create: `test/test_config/test_main.cpp`

**Interfaces:**
- Consumes: `Level`, `moisturePercent`, `classify` aus Task 1.
- Produces:
  ```cpp
  bool parseIpv4(const char* s, uint8_t out[4]);       // ipv4.h; out darf nullptr sein
  struct Config {
    char ssid[33]; char wifiPassword[65];
    char staticIp[16]; char gateway[16]; char subnet[16]; char dns[16];
    char mqttHost[65]; uint16_t mqttPort; char mqttUser[33]; char mqttPassword[65];
    char topicPrefix[33]; char deviceName[33];
    int dryRaw; int wetRaw; int dryBelowPct; int wetAbovePct; int intervalMin;
  };
  Config defaultConfig();
  bool configIsValid(const Config& c);                   // ssid und mqttHost nicht leer
  // Liest JSON ueber io. Fehlende Felder bleiben, wie sie in io stehen.
  // Leere Passwort-Strings ueberschreiben nicht. Zahlen werden begrenzt.
  // false bei unparsbarem JSON, io bleibt dann unveraendert.
  bool parseConfig(const char* json, Config& io);
  // nullptr wenn gueltig, sonst deutscher Fehlertext
  const char* validateConfig(const Config& c);
  // Schreibt JSON nach buf. maskSecrets: Passwoerter leer, dazu
  // wifiPasswordSet/mqttPasswordSet. Rueckgabe 0, wenn buf zu klein.
  size_t serializeConfig(const Config& c, char* buf, size_t n, bool maskSecrets);
  constexpr size_t CONFIG_JSON_SIZE = 1024;

  struct Reading { int raw; int percent; Level level; };
  Reading evaluateReading(int raw, const Config& c);
  ```

- [ ] **Step 0a: Fehlschlagenden Test für den IPv4-Parser schreiben**

`test/test_ipv4/test_main.cpp`:

```cpp
#include <unity.h>
#include "ipv4.h"

void setUp() {}
void tearDown() {}

void test_valid_addresses() {
  uint8_t b[4];
  TEST_ASSERT_TRUE(parseIpv4("192.168.1.42", b));
  TEST_ASSERT_EQUAL_UINT8(192, b[0]);
  TEST_ASSERT_EQUAL_UINT8(168, b[1]);
  TEST_ASSERT_EQUAL_UINT8(1, b[2]);
  TEST_ASSERT_EQUAL_UINT8(42, b[3]);
  TEST_ASSERT_TRUE(parseIpv4("0.0.0.0", b));
  TEST_ASSERT_TRUE(parseIpv4("255.255.255.0", b));
  TEST_ASSERT_TRUE(parseIpv4("10.0.0.1", nullptr));
}

void test_invalid_addresses() {
  TEST_ASSERT_FALSE(parseIpv4("", nullptr));
  TEST_ASSERT_FALSE(parseIpv4(nullptr, nullptr));
  TEST_ASSERT_FALSE(parseIpv4("192.168.1", nullptr));
  TEST_ASSERT_FALSE(parseIpv4("192.168.1.256", nullptr));
  TEST_ASSERT_FALSE(parseIpv4("192.168.1.1.1", nullptr));
  TEST_ASSERT_FALSE(parseIpv4("192.168..1", nullptr));
  TEST_ASSERT_FALSE(parseIpv4("abc.def.ghi.jkl", nullptr));
  TEST_ASSERT_FALSE(parseIpv4("192.168.1.42 ", nullptr));
  TEST_ASSERT_FALSE(parseIpv4("1234.1.1.1", nullptr));
}

int main(int, char**) {
  UNITY_BEGIN();
  RUN_TEST(test_valid_addresses);
  RUN_TEST(test_invalid_addresses);
  return UNITY_END();
}
```

- [ ] **Step 0b: Test laufen lassen, Fehlschlag prüfen**

```bash
pio test -e native -f test_ipv4
```

Erwartet: Build-Fehler `ipv4.h: No such file or directory`.

- [ ] **Step 0c: ipv4.h schreiben**

`src/ipv4.h`:

```cpp
#pragma once
#include <stdint.h>

// Prueft einen IPv4-String der Form "a.b.c.d" (nur Ziffern und Punkte,
// jede Gruppe 1..3 Ziffern, Wert 0..255). out darf nullptr sein.
inline bool parseIpv4(const char* s, uint8_t out[4]) {
  if (s == nullptr || *s == '\0') return false;
  int part = 0;
  int value = 0;
  int digits = 0;
  uint8_t tmp[4] = {0, 0, 0, 0};
  for (const char* p = s;; p++) {
    char c = *p;
    if (c >= '0' && c <= '9') {
      if (++digits > 3) return false;
      value = value * 10 + (c - '0');
      if (value > 255) return false;
    } else if (c == '.' || c == '\0') {
      if (digits == 0 || part > 3) return false;
      tmp[part++] = (uint8_t)value;
      value = 0;
      digits = 0;
      if (c == '\0') break;
    } else {
      return false;
    }
  }
  if (part != 4) return false;
  if (out != nullptr) {
    for (int i = 0; i < 4; i++) out[i] = tmp[i];
  }
  return true;
}
```

- [ ] **Step 0d: Test laufen lassen, Erfolg prüfen**

```bash
pio test -e native -f test_ipv4
```

Erwartet: `2 Tests 0 Failures`.

- [ ] **Step 1: Fehlschlagenden Test schreiben**

`test/test_config/test_main.cpp`:

```cpp
#include <unity.h>
#include <string.h>
#include "config.h"
#include "moisture.h"

void setUp() {}
void tearDown() {}

void test_defaults() {
  Config c = defaultConfig();
  TEST_ASSERT_EQUAL_STRING("", c.ssid);
  TEST_ASSERT_EQUAL_STRING("", c.mqttHost);
  TEST_ASSERT_EQUAL_UINT16(1883, c.mqttPort);
  TEST_ASSERT_EQUAL_STRING("soil", c.topicPrefix);
  TEST_ASSERT_EQUAL_STRING("sensor1", c.deviceName);
  TEST_ASSERT_EQUAL_INT(226, c.dryRaw);
  TEST_ASSERT_EQUAL_INT(181, c.wetRaw);
  TEST_ASSERT_EQUAL_INT(30, c.dryBelowPct);
  TEST_ASSERT_EQUAL_INT(70, c.wetAbovePct);
  TEST_ASSERT_EQUAL_INT(15, c.intervalMin);
  TEST_ASSERT_EQUAL_STRING("", c.staticIp);
  TEST_ASSERT_EQUAL_STRING("", c.gateway);
  TEST_ASSERT_EQUAL_STRING("255.255.255.0", c.subnet);
  TEST_ASSERT_EQUAL_STRING("", c.dns);
  TEST_ASSERT_FALSE(configIsValid(c));
}

void test_valid_needs_ssid_and_host() {
  Config c = defaultConfig();
  strcpy(c.ssid, "Garten");
  TEST_ASSERT_FALSE(configIsValid(c));
  strcpy(c.mqttHost, "192.168.1.10");
  TEST_ASSERT_TRUE(configIsValid(c));
}

void test_parse_full_json() {
  Config c = defaultConfig();
  const char* json =
    "{\"ssid\":\"Garten\",\"wifiPassword\":\"geheim\",\"mqttHost\":\"broker\","
    "\"mqttPort\":8883,\"mqttUser\":\"u\",\"mqttPassword\":\"p\",\"topicPrefix\":\"haus\","
    "\"deviceName\":\"beet2\",\"dryRaw\":300,\"wetRaw\":150,\"dryBelowPct\":20,"
    "\"wetAbovePct\":80,\"intervalMin\":30}";
  TEST_ASSERT_TRUE(parseConfig(json, c));
  TEST_ASSERT_EQUAL_STRING("Garten", c.ssid);
  TEST_ASSERT_EQUAL_STRING("geheim", c.wifiPassword);
  TEST_ASSERT_EQUAL_STRING("broker", c.mqttHost);
  TEST_ASSERT_EQUAL_UINT16(8883, c.mqttPort);
  TEST_ASSERT_EQUAL_STRING("u", c.mqttUser);
  TEST_ASSERT_EQUAL_STRING("p", c.mqttPassword);
  TEST_ASSERT_EQUAL_STRING("haus", c.topicPrefix);
  TEST_ASSERT_EQUAL_STRING("beet2", c.deviceName);
  TEST_ASSERT_EQUAL_INT(300, c.dryRaw);
  TEST_ASSERT_EQUAL_INT(150, c.wetRaw);
  TEST_ASSERT_EQUAL_INT(20, c.dryBelowPct);
  TEST_ASSERT_EQUAL_INT(80, c.wetAbovePct);
  TEST_ASSERT_EQUAL_INT(30, c.intervalMin);
}

void test_parse_partial_json_keeps_rest() {
  Config c = defaultConfig();
  strcpy(c.ssid, "Alt");
  TEST_ASSERT_TRUE(parseConfig("{\"intervalMin\":5}", c));
  TEST_ASSERT_EQUAL_INT(5, c.intervalMin);
  TEST_ASSERT_EQUAL_STRING("Alt", c.ssid);
  TEST_ASSERT_EQUAL_INT(226, c.dryRaw);
}

void test_parse_empty_object_and_garbage() {
  Config c = defaultConfig();
  TEST_ASSERT_TRUE(parseConfig("{}", c));
  TEST_ASSERT_EQUAL_INT(15, c.intervalMin);
  strcpy(c.ssid, "Bleibt");
  TEST_ASSERT_FALSE(parseConfig("kein json", c));
  TEST_ASSERT_EQUAL_STRING("Bleibt", c.ssid);
  TEST_ASSERT_FALSE(parseConfig("", c));
}

void test_parse_empty_password_keeps_old() {
  Config c = defaultConfig();
  strcpy(c.wifiPassword, "alt1");
  strcpy(c.mqttPassword, "alt2");
  TEST_ASSERT_TRUE(parseConfig("{\"wifiPassword\":\"\",\"mqttPassword\":\"\",\"ssid\":\"\"}", c));
  TEST_ASSERT_EQUAL_STRING("alt1", c.wifiPassword);
  TEST_ASSERT_EQUAL_STRING("alt2", c.mqttPassword);
  TEST_ASSERT_EQUAL_STRING("", c.ssid);   // nur Passwoerter sind geschuetzt
}

void test_parse_clamps_numbers() {
  Config c = defaultConfig();
  TEST_ASSERT_TRUE(parseConfig("{\"intervalMin\":0,\"dryBelowPct\":-5,\"wetAbovePct\":150}", c));
  TEST_ASSERT_EQUAL_INT(1, c.intervalMin);
  TEST_ASSERT_EQUAL_INT(0, c.dryBelowPct);
  TEST_ASSERT_EQUAL_INT(100, c.wetAbovePct);
  TEST_ASSERT_TRUE(parseConfig("{\"intervalMin\":999}", c));
  TEST_ASSERT_EQUAL_INT(180, c.intervalMin);
}

void test_parse_truncates_long_strings() {
  Config c = defaultConfig();
  char json[200];
  char longSsid[50];
  memset(longSsid, 'a', 49); longSsid[49] = '\0';
  snprintf(json, sizeof json, "{\"ssid\":\"%s\"}", longSsid);
  TEST_ASSERT_TRUE(parseConfig(json, c));
  TEST_ASSERT_EQUAL_INT(32, (int)strlen(c.ssid));
}

void test_validate_thresholds() {
  Config c = defaultConfig();
  TEST_ASSERT_NULL(validateConfig(c));
  c.dryBelowPct = 70; c.wetAbovePct = 70;
  TEST_ASSERT_NOT_NULL(validateConfig(c));
  c.dryBelowPct = 80;
  TEST_ASSERT_NOT_NULL(validateConfig(c));
}

void test_parse_static_ip_fields() {
  Config c = defaultConfig();
  TEST_ASSERT_TRUE(parseConfig(
    "{\"staticIp\":\"192.168.1.50\",\"gateway\":\"192.168.1.1\",\"subnet\":\"255.255.0.0\",\"dns\":\"1.1.1.1\"}", c));
  TEST_ASSERT_EQUAL_STRING("192.168.1.50", c.staticIp);
  TEST_ASSERT_EQUAL_STRING("192.168.1.1", c.gateway);
  TEST_ASSERT_EQUAL_STRING("255.255.0.0", c.subnet);
  TEST_ASSERT_EQUAL_STRING("1.1.1.1", c.dns);
}

void test_validate_static_ip() {
  Config c = defaultConfig();
  // DHCP: Gateway darf beliebig sein
  strcpy(c.gateway, "unsinn");
  TEST_ASSERT_NULL(validateConfig(c));
  // statische IP ohne Gateway ist ein Fehler
  strcpy(c.staticIp, "192.168.1.50");
  strcpy(c.gateway, "");
  TEST_ASSERT_NOT_NULL(validateConfig(c));
  // ungueltige IP
  strcpy(c.gateway, "192.168.1.1");
  strcpy(c.staticIp, "192.168.1.300");
  TEST_ASSERT_NOT_NULL(validateConfig(c));
  // ungueltige Maske
  strcpy(c.staticIp, "192.168.1.50");
  strcpy(c.subnet, "255.255.255");
  TEST_ASSERT_NOT_NULL(validateConfig(c));
  // alles gueltig, DNS leer ist erlaubt
  strcpy(c.subnet, "255.255.255.0");
  TEST_ASSERT_NULL(validateConfig(c));
  // DNS gesetzt, aber ungueltig
  strcpy(c.dns, "dns.local");
  TEST_ASSERT_NOT_NULL(validateConfig(c));
}

void test_serialize_roundtrip() {
  Config c = defaultConfig();
  strcpy(c.ssid, "Garten"); strcpy(c.wifiPassword, "pw");
  strcpy(c.mqttHost, "broker"); strcpy(c.mqttPassword, "mp");
  strcpy(c.staticIp, "10.0.0.5"); strcpy(c.gateway, "10.0.0.1"); strcpy(c.dns, "10.0.0.1");
  c.intervalMin = 42;
  char buf[CONFIG_JSON_SIZE];
  size_t n = serializeConfig(c, buf, sizeof buf, false);
  TEST_ASSERT_TRUE(n > 0);
  Config back = defaultConfig();
  TEST_ASSERT_TRUE(parseConfig(buf, back));
  TEST_ASSERT_EQUAL_STRING("Garten", back.ssid);
  TEST_ASSERT_EQUAL_STRING("pw", back.wifiPassword);
  TEST_ASSERT_EQUAL_STRING("mp", back.mqttPassword);
  TEST_ASSERT_EQUAL_STRING("10.0.0.5", back.staticIp);
  TEST_ASSERT_EQUAL_STRING("10.0.0.1", back.gateway);
  TEST_ASSERT_EQUAL_STRING("255.255.255.0", back.subnet);
  TEST_ASSERT_EQUAL_STRING("10.0.0.1", back.dns);
  TEST_ASSERT_EQUAL_INT(42, back.intervalMin);
}

void test_serialize_masks_secrets() {
  Config c = defaultConfig();
  strcpy(c.wifiPassword, "pw");
  char buf[CONFIG_JSON_SIZE];
  TEST_ASSERT_TRUE(serializeConfig(c, buf, sizeof buf, true) > 0);
  TEST_ASSERT_NULL(strstr(buf, "\"pw\""));
  TEST_ASSERT_NOT_NULL(strstr(buf, "\"wifiPassword\":\"\""));
  TEST_ASSERT_NOT_NULL(strstr(buf, "\"wifiPasswordSet\":true"));
  TEST_ASSERT_NOT_NULL(strstr(buf, "\"mqttPasswordSet\":false"));
}

void test_serialize_too_small_buffer_returns_zero() {
  Config c = defaultConfig();
  char buf[16];
  TEST_ASSERT_EQUAL_UINT(0, serializeConfig(c, buf, sizeof buf, false));
}

void test_evaluate_reading() {
  Config c = defaultConfig();
  Reading r = evaluateReading(226, c);
  TEST_ASSERT_EQUAL_INT(226, r.raw);
  TEST_ASSERT_EQUAL_INT(0, r.percent);
  TEST_ASSERT_EQUAL(Level::Dry, r.level);
  r = evaluateReading(181, c);
  TEST_ASSERT_EQUAL_INT(100, r.percent);
  TEST_ASSERT_EQUAL(Level::Wet, r.level);
}

int main(int, char**) {
  UNITY_BEGIN();
  RUN_TEST(test_defaults);
  RUN_TEST(test_valid_needs_ssid_and_host);
  RUN_TEST(test_parse_full_json);
  RUN_TEST(test_parse_partial_json_keeps_rest);
  RUN_TEST(test_parse_empty_object_and_garbage);
  RUN_TEST(test_parse_empty_password_keeps_old);
  RUN_TEST(test_parse_clamps_numbers);
  RUN_TEST(test_parse_truncates_long_strings);
  RUN_TEST(test_validate_thresholds);
  RUN_TEST(test_parse_static_ip_fields);
  RUN_TEST(test_validate_static_ip);
  RUN_TEST(test_serialize_roundtrip);
  RUN_TEST(test_serialize_masks_secrets);
  RUN_TEST(test_serialize_too_small_buffer_returns_zero);
  RUN_TEST(test_evaluate_reading);
  return UNITY_END();
}
```

- [ ] **Step 2: Test laufen lassen, Fehlschlag prüfen**

```bash
pio test -e native -f test_config
```

Erwartet: Build-Fehler `config.h: No such file or directory`.

- [ ] **Step 3: config.h schreiben**

`src/config.h`:

```cpp
#pragma once
#include <stddef.h>
#include <stdint.h>

// Alle Einstellungen des Sensors. Quelle ist /config.json im LittleFS.
// Dieser Header ist Arduino-frei; nur loadConfig/saveConfig brauchen das Geraet.

struct Config {
  char ssid[33];
  char wifiPassword[65];
  char staticIp[16];     // leer = DHCP
  char gateway[16];
  char subnet[16];
  char dns[16];          // leer = Gateway
  char mqttHost[65];
  uint16_t mqttPort;
  char mqttUser[33];
  char mqttPassword[65];
  char topicPrefix[33];
  char deviceName[33];
  int dryRaw;
  int wetRaw;
  int dryBelowPct;
  int wetAbovePct;
  int intervalMin;
};

// Groesse eines Puffers, der serializeConfig sicher aufnimmt
constexpr size_t CONFIG_JSON_SIZE = 1024;
constexpr int INTERVAL_MIN_MINUTES = 1;
constexpr int INTERVAL_MAX_MINUTES = 180;

Config defaultConfig();

// Gueltig, wenn SSID und MQTT-Host gesetzt sind
bool configIsValid(const Config& c);

// Liest JSON ueber io. Fehlende Felder bleiben, wie sie in io stehen.
// Leere Passwort-Strings ueberschreiben nicht. Zahlen werden begrenzt.
// Liefert false bei unparsbarem JSON; io bleibt dann unveraendert.
bool parseConfig(const char* json, Config& io);

// nullptr, wenn gueltig, sonst ein deutscher Fehlertext fuer die API
const char* validateConfig(const Config& c);

// Schreibt die Konfiguration als JSON nach buf. Bei maskSecrets werden die
// Passwoerter leer ausgegeben und wifiPasswordSet/mqttPasswordSet ergaenzt.
// Rueckgabe: Laenge, oder 0, wenn buf zu klein ist.
size_t serializeConfig(const Config& c, char* buf, size_t n, bool maskSecrets);

// Nur auf dem Geraet (LittleFS). Implementierung in config.cpp unter #ifdef ARDUINO.
bool loadConfig(Config& io);          // false, wenn Datei fehlt oder unlesbar; io behaelt Standardwerte
bool saveConfig(const Config& c);     // false bei Schreibfehler
```

- [ ] **Step 4: config.cpp schreiben (Arduino-freier Teil)**

`src/config.cpp`:

```cpp
#include "config.h"
#include "ipv4.h"
#include <ArduinoJson.h>
#include <stdio.h>
#include <string.h>

static void setStr(char* dst, size_t n, const char* src) {
  snprintf(dst, n, "%s", src ? src : "");
}

static int clampInt(int v, int lo, int hi) {
  return v < lo ? lo : (v > hi ? hi : v);
}

Config defaultConfig() {
  Config c;
  memset(&c, 0, sizeof c);
  c.mqttPort = 1883;
  setStr(c.subnet, sizeof c.subnet, "255.255.255.0");
  setStr(c.topicPrefix, sizeof c.topicPrefix, "soil");
  setStr(c.deviceName, sizeof c.deviceName, "sensor1");
  c.dryRaw = 226;
  c.wetRaw = 181;
  c.dryBelowPct = 30;
  c.wetAbovePct = 70;
  c.intervalMin = 15;
  return c;
}

bool configIsValid(const Config& c) {
  return c.ssid[0] != '\0' && c.mqttHost[0] != '\0';
}

// Uebernimmt einen JSON-String in dst, wenn er vorhanden ist.
// keepIfEmpty: leerer String laesst dst unveraendert (fuer Passwoerter).
static void readStr(JsonVariantConst v, char* dst, size_t n, bool keepIfEmpty) {
  if (!v.is<const char*>()) return;
  const char* s = v.as<const char*>();
  if (s == nullptr) return;
  if (keepIfEmpty && s[0] == '\0') return;
  setStr(dst, n, s);
}

static void readInt(JsonVariantConst v, int& dst) {
  if (v.is<int>()) dst = v.as<int>();
}

bool parseConfig(const char* json, Config& io) {
  if (json == nullptr) return false;
  JsonDocument doc;
  DeserializationError err = deserializeJson(doc, json);
  if (err || !doc.is<JsonObjectConst>()) return false;
  JsonObjectConst o = doc.as<JsonObjectConst>();

  readStr(o["ssid"],         io.ssid,         sizeof io.ssid,         false);
  readStr(o["wifiPassword"], io.wifiPassword, sizeof io.wifiPassword, true);
  readStr(o["staticIp"],     io.staticIp,     sizeof io.staticIp,     false);
  readStr(o["gateway"],      io.gateway,      sizeof io.gateway,      false);
  readStr(o["subnet"],       io.subnet,       sizeof io.subnet,       false);
  readStr(o["dns"],          io.dns,          sizeof io.dns,          false);
  readStr(o["mqttHost"],     io.mqttHost,     sizeof io.mqttHost,     false);
  readStr(o["mqttUser"],     io.mqttUser,     sizeof io.mqttUser,     false);
  readStr(o["mqttPassword"], io.mqttPassword, sizeof io.mqttPassword, true);
  readStr(o["topicPrefix"],  io.topicPrefix,  sizeof io.topicPrefix,  false);
  readStr(o["deviceName"],   io.deviceName,   sizeof io.deviceName,   false);

  int port = io.mqttPort;
  readInt(o["mqttPort"], port);
  io.mqttPort = (uint16_t)clampInt(port, 1, 65535);

  readInt(o["dryRaw"], io.dryRaw);
  readInt(o["wetRaw"], io.wetRaw);
  readInt(o["dryBelowPct"], io.dryBelowPct);
  readInt(o["wetAbovePct"], io.wetAbovePct);
  readInt(o["intervalMin"], io.intervalMin);

  io.dryBelowPct = clampInt(io.dryBelowPct, 0, 100);
  io.wetAbovePct = clampInt(io.wetAbovePct, 0, 100);
  io.intervalMin = clampInt(io.intervalMin, INTERVAL_MIN_MINUTES, INTERVAL_MAX_MINUTES);
  return true;
}

const char* validateConfig(const Config& c) {
  if (c.dryBelowPct >= c.wetAbovePct) return "Schwelle 'trocken unter' muss kleiner sein als 'nass ab'";
  if (c.deviceName[0] == '\0') return "Geraetename darf nicht leer sein";
  if (c.topicPrefix[0] == '\0') return "Topic-Praefix darf nicht leer sein";
  if (c.staticIp[0] != '\0') {
    if (!parseIpv4(c.staticIp, nullptr)) return "Statische IP ist keine gueltige IPv4-Adresse";
    if (!parseIpv4(c.gateway, nullptr)) return "Gateway fehlt oder ist keine gueltige IPv4-Adresse";
    if (!parseIpv4(c.subnet, nullptr)) return "Subnetzmaske ist keine gueltige IPv4-Adresse";
    if (c.dns[0] != '\0' && !parseIpv4(c.dns, nullptr)) return "DNS ist keine gueltige IPv4-Adresse";
  }
  return nullptr;
}

size_t serializeConfig(const Config& c, char* buf, size_t n, bool maskSecrets) {
  JsonDocument doc;
  doc["ssid"] = c.ssid;
  doc["wifiPassword"] = maskSecrets ? "" : c.wifiPassword;
  doc["staticIp"] = c.staticIp;
  doc["gateway"] = c.gateway;
  doc["subnet"] = c.subnet;
  doc["dns"] = c.dns;
  doc["mqttHost"] = c.mqttHost;
  doc["mqttPort"] = c.mqttPort;
  doc["mqttUser"] = c.mqttUser;
  doc["mqttPassword"] = maskSecrets ? "" : c.mqttPassword;
  doc["topicPrefix"] = c.topicPrefix;
  doc["deviceName"] = c.deviceName;
  doc["dryRaw"] = c.dryRaw;
  doc["wetRaw"] = c.wetRaw;
  doc["dryBelowPct"] = c.dryBelowPct;
  doc["wetAbovePct"] = c.wetAbovePct;
  doc["intervalMin"] = c.intervalMin;
  if (maskSecrets) {
    doc["wifiPasswordSet"] = c.wifiPassword[0] != '\0';
    doc["mqttPasswordSet"] = c.mqttPassword[0] != '\0';
  }
  size_t need = measureJson(doc);
  if (need + 1 > n) return 0;
  return serializeJson(doc, buf, n);
}

#ifdef ARDUINO
// LittleFS-Teil folgt in Task 5
#endif
```

- [ ] **Step 5: Reading und evaluateReading in moisture.h ergänzen**

Am Ende von `src/moisture.h` anfügen:

```cpp
#include "config.h"

struct Reading {
  int raw;
  int percent;
  Level level;
};

inline Reading evaluateReading(int raw, const Config& c) {
  Reading r;
  r.raw = raw;
  r.percent = moisturePercent(raw, c.dryRaw, c.wetRaw);
  r.level = classify(r.percent, c.dryBelowPct, c.wetAbovePct);
  return r;
}
```

- [ ] **Step 6: Tests laufen lassen, Erfolg prüfen**

```bash
pio test -e native
```

Erwartet: alle vier Testgruppen `PASSED`, test_config mit `15 Tests 0 Failures`.

Bekannte Stolperstelle: Wenn `v.is<const char*>()` bei ArduinoJson 7 nicht kompiliert, stattdessen `v.is<JsonString>()` und `v.as<const char*>()` verwenden.

- [ ] **Step 7: Commit**

```bash
git add src/ipv4.h test/test_ipv4/test_main.cpp src/config.h src/config.cpp src/moisture.h test/test_config/test_main.cpp
git commit -m "feat: Konfigurationsstruktur mit JSON-Konvertierung, Validierung und IPv4-Parser"
```

---

### Task 4: MQTT-Topic und Payload

**Files:**
- Create: `src/mqtt_payload.h`
- Create: `test/test_mqtt_payload/test_main.cpp`

**Interfaces:**
- Consumes: `Config`, `Reading`, `levelName` aus Task 1 und 3.
- Produces:
  ```cpp
  size_t buildStateTopic(const Config& c, char* buf, size_t n);                       // "<prefix>/<name>/state"
  size_t buildStatePayload(const Reading& r, int rssi, bool test, char* buf, size_t n);
  constexpr size_t MQTT_TOPIC_SIZE = 80;
  constexpr size_t MQTT_PAYLOAD_SIZE = 128;
  ```

- [ ] **Step 1: Fehlschlagenden Test schreiben**

`test/test_mqtt_payload/test_main.cpp`:

```cpp
#include <unity.h>
#include <string.h>
#include "mqtt_payload.h"

void setUp() {}
void tearDown() {}

void test_topic() {
  Config c = defaultConfig();
  char buf[MQTT_TOPIC_SIZE];
  TEST_ASSERT_TRUE(buildStateTopic(c, buf, sizeof buf) > 0);
  TEST_ASSERT_EQUAL_STRING("soil/sensor1/state", buf);
  strcpy(c.topicPrefix, "haus/garten");
  strcpy(c.deviceName, "beet2");
  buildStateTopic(c, buf, sizeof buf);
  TEST_ASSERT_EQUAL_STRING("haus/garten/beet2/state", buf);
}

void test_payload_without_test_flag() {
  Reading r = { 202, 54, Level::Ok };
  char buf[MQTT_PAYLOAD_SIZE];
  TEST_ASSERT_TRUE(buildStatePayload(r, -61, false, buf, sizeof buf) > 0);
  TEST_ASSERT_EQUAL_STRING("{\"raw\":202,\"percent\":54,\"level\":\"ok\",\"rssi\":-61}", buf);
}

void test_payload_with_test_flag() {
  Reading r = { 218, 18, Level::Dry };
  char buf[MQTT_PAYLOAD_SIZE];
  buildStatePayload(r, -70, true, buf, sizeof buf);
  TEST_ASSERT_EQUAL_STRING("{\"raw\":218,\"percent\":18,\"level\":\"dry\",\"rssi\":-70,\"test\":true}", buf);
}

int main(int, char**) {
  UNITY_BEGIN();
  RUN_TEST(test_topic);
  RUN_TEST(test_payload_without_test_flag);
  RUN_TEST(test_payload_with_test_flag);
  return UNITY_END();
}
```

- [ ] **Step 2: Test laufen lassen, Fehlschlag prüfen**

```bash
pio test -e native -f test_mqtt_payload
```

Erwartet: Build-Fehler `mqtt_payload.h: No such file or directory`.

- [ ] **Step 3: mqtt_payload.h schreiben**

`src/mqtt_payload.h`:

```cpp
#pragma once
#include <stdio.h>
#include "config.h"
#include "moisture.h"

constexpr size_t MQTT_TOPIC_SIZE = 80;
constexpr size_t MQTT_PAYLOAD_SIZE = 128;

// "<topicPrefix>/<deviceName>/state"
inline size_t buildStateTopic(const Config& c, char* buf, size_t n) {
  int len = snprintf(buf, n, "%s/%s/state", c.topicPrefix, c.deviceName);
  return len < 0 ? 0 : (size_t)len;
}

// {"raw":N,"percent":N,"level":"dry|ok|wet","rssi":N[,"test":true]}
inline size_t buildStatePayload(const Reading& r, int rssi, bool test, char* buf, size_t n) {
  int len = snprintf(buf, n, "{\"raw\":%d,\"percent\":%d,\"level\":\"%s\",\"rssi\":%d%s}",
                     r.raw, r.percent, levelName(r.level), rssi, test ? ",\"test\":true" : "");
  return len < 0 ? 0 : (size_t)len;
}
```

- [ ] **Step 4: Test laufen lassen, Erfolg prüfen**

```bash
pio test -e native -f test_mqtt_payload
```

Erwartet: `3 Tests 0 Failures`.

- [ ] **Step 5: Commit**

```bash
git add src/mqtt_payload.h test/test_mqtt_payload/test_main.cpp
git commit -m "feat: MQTT-Topic und Payload als testbare Funktionen"
```

---

### Task 5: LittleFS-Speicherung, WLAN-Station und MQTT-Sender (Gerätecode)

**Files:**
- Modify: `src/config.cpp` (Block `#ifdef ARDUINO`)
- Create: `src/wifi_station.h`
- Create: `src/wifi_station.cpp`
- Create: `src/mqtt_sender.h`
- Create: `src/mqtt_sender.cpp`

**Interfaces:**
- Consumes: `Config`, `serializeConfig`, `parseConfig`, `buildStateTopic`, `buildStatePayload`, `Reading`.
- Produces:
  ```cpp
  bool loadConfig(Config& io);        // aus config.h, LittleFS muss gemountet sein
  bool saveConfig(const Config& c);
  // Wendet die statische IP aus cfg an (falls gesetzt) und startet WiFi.begin.
  // Nicht blockierend. false, wenn keine SSID gesetzt ist.
  bool beginStation(const Config& cfg);
  // Verbindet mit dem Broker aus cfg, veroeffentlicht retained, trennt wieder.
  // Bei Fehler: false und deutscher Text in err.
  bool mqttPublishReading(const Config& cfg, const Reading& r, int rssi, bool test, char* err, size_t errLen);
  ```

Diese Funktionen laufen nur am Gerät; der Test in diesem Task ist ein sauberer Build. Funktionstest folgt in Task 7 am Gerät.

- [ ] **Step 1: LittleFS-Teil in config.cpp ergänzen**

Den Block `#ifdef ARDUINO ... #endif` am Ende von `src/config.cpp` ersetzen durch:

```cpp
#ifdef ARDUINO
#include <Arduino.h>
#include <LittleFS.h>

static const char* CONFIG_PATH = "/config.json";

bool loadConfig(Config& io) {
  File f = LittleFS.open(CONFIG_PATH, "r");
  if (!f) {
    Serial.println("Keine config.json, Standardwerte");
    return false;
  }
  char buf[CONFIG_JSON_SIZE];
  size_t n = f.readBytes(buf, sizeof buf - 1);
  buf[n] = '\0';
  f.close();
  if (!parseConfig(buf, io)) {
    Serial.println("config.json unlesbar, Standardwerte");
    return false;
  }
  return true;
}

bool saveConfig(const Config& c) {
  char buf[CONFIG_JSON_SIZE];
  size_t n = serializeConfig(c, buf, sizeof buf, false);
  if (n == 0) return false;
  File f = LittleFS.open(CONFIG_PATH, "w");
  if (!f) {
    Serial.println("config.json kann nicht geschrieben werden");
    return false;
  }
  size_t written = f.write((const uint8_t*)buf, n);
  f.close();
  return written == n;
}
#endif
```

- [ ] **Step 1b: wifi_station.h schreiben**

`src/wifi_station.h`:

```cpp
#pragma once
#include "config.h"

// Startet die Verbindung zum Heimnetz aus cfg. Ist staticIp gesetzt, wird
// vorher WiFi.config() mit IP, Gateway, Subnetz und DNS (leer = Gateway)
// aufgerufen; sonst DHCP. Nicht blockierend: Aufrufer prueft WiFi.status().
// Rueckgabe false, wenn keine SSID gesetzt ist.
bool beginStation(const Config& cfg);
```

- [ ] **Step 1c: wifi_station.cpp schreiben**

`src/wifi_station.cpp`:

```cpp
#include "wifi_station.h"
#include <Arduino.h>
#include <ESP8266WiFi.h>
#include "ipv4.h"

static IPAddress toIp(const char* s) {
  uint8_t b[4] = {0, 0, 0, 0};
  parseIpv4(s, b);
  return IPAddress(b[0], b[1], b[2], b[3]);
}

bool beginStation(const Config& cfg) {
  if (cfg.ssid[0] == '\0') return false;
  if (cfg.staticIp[0] != '\0' && parseIpv4(cfg.staticIp, nullptr) &&
      parseIpv4(cfg.gateway, nullptr) && parseIpv4(cfg.subnet, nullptr)) {
    IPAddress dns = cfg.dns[0] != '\0' && parseIpv4(cfg.dns, nullptr) ? toIp(cfg.dns) : toIp(cfg.gateway);
    WiFi.config(toIp(cfg.staticIp), toIp(cfg.gateway), toIp(cfg.subnet), dns);
    Serial.printf("Statische IP %s\n", cfg.staticIp);
  } else {
    // Zurueck auf DHCP, falls vorher eine statische Adresse gesetzt war
    WiFi.config(IPAddress(0, 0, 0, 0), IPAddress(0, 0, 0, 0), IPAddress(0, 0, 0, 0));
  }
  WiFi.begin(cfg.ssid, cfg.wifiPassword);
  return true;
}
```

- [ ] **Step 2: mqtt_sender.h schreiben**

`src/mqtt_sender.h`:

```cpp
#pragma once
#include <stddef.h>
#include "config.h"
#include "moisture.h"

// Verbindet mit dem Broker aus cfg, veroeffentlicht die Messung retained auf
// <topicPrefix>/<deviceName>/state und trennt wieder. Blockiert hoechstens
// etwa 5 s pro Schritt (Socket-Timeout).
// Rueckgabe false bei Fehler, err enthaelt dann einen deutschen Text.
bool mqttPublishReading(const Config& cfg, const Reading& r, int rssi, bool test,
                        char* err, size_t errLen);
```

- [ ] **Step 3: mqtt_sender.cpp schreiben**

`src/mqtt_sender.cpp`:

```cpp
#include "mqtt_sender.h"
#include <Arduino.h>
#include <ESP8266WiFi.h>
#include <PubSubClient.h>
#include "mqtt_payload.h"

static const uint16_t MQTT_SOCKET_TIMEOUT_S = 5;

bool mqttPublishReading(const Config& cfg, const Reading& r, int rssi, bool test,
                        char* err, size_t errLen) {
  WiFiClient net;
  net.setTimeout(MQTT_SOCKET_TIMEOUT_S * 1000);
  PubSubClient mqtt(net);
  mqtt.setServer(cfg.mqttHost, cfg.mqttPort);
  mqtt.setSocketTimeout(MQTT_SOCKET_TIMEOUT_S);

  const char* user = cfg.mqttUser[0] ? cfg.mqttUser : nullptr;
  const char* pass = cfg.mqttPassword[0] ? cfg.mqttPassword : nullptr;
  if (!mqtt.connect(cfg.deviceName, user, pass)) {
    snprintf(err, errLen, "MQTT-Verbindung zu %s:%u fehlgeschlagen (Code %d)",
             cfg.mqttHost, cfg.mqttPort, mqtt.state());
    return false;
  }

  char topic[MQTT_TOPIC_SIZE];
  char payload[MQTT_PAYLOAD_SIZE];
  buildStateTopic(cfg, topic, sizeof topic);
  buildStatePayload(r, rssi, test, payload, sizeof payload);

  bool ok = mqtt.publish(topic, payload, true);
  mqtt.loop();
  mqtt.disconnect();
  if (!ok) {
    snprintf(err, errLen, "Veroeffentlichen auf %s fehlgeschlagen", topic);
    return false;
  }
  Serial.printf("MQTT %s <- %s\n", topic, payload);
  return true;
}
```

- [ ] **Step 4: Build am Gerät prüfen**

```bash
pio run -e esp12e
```

Erwartet: `SUCCESS`. Falls `LittleFS.h` nicht gefunden wird, fehlt `board_build.filesystem = littlefs` in `platformio.ini` (Task 1).

- [ ] **Step 5: Native Tests laufen weiterhin**

```bash
pio test -e native
```

Erwartet: alle `PASSED` (der `#ifdef ARDUINO`-Block wird nativ nicht kompiliert).

- [ ] **Step 6: Commit**

```bash
git add src/config.cpp src/wifi_station.h src/wifi_station.cpp src/mqtt_sender.h src/mqtt_sender.cpp
git commit -m "feat: Konfiguration im LittleFS speichern, WLAN-Station mit statischer IP, MQTT-Sender"
```

---

### Task 6: HTML-Seite und Webserver

**Files:**
- Create: `src/index_html.h`
- Create: `src/web_ui.h`
- Create: `src/web_ui.cpp`

**Interfaces:**
- Consumes: `Config`, `parseConfig`, `validateConfig`, `serializeConfig`, `saveConfig`, `mqttPublishReading`, `evaluateReading`.
- Produces:
  ```cpp
  class WebUi {
   public:
    WebUi(Config& cfg, unsigned long idleTimeoutMs);
    void begin();                       // Routen registrieren, Server starten
    void handle();                      // in der Schleife aufrufen
    void setRaw(int raw);               // aktueller Rohwert fuer /api/status
    bool shouldExit() const;            // Timeout abgelaufen oder /api/sleep
    int secondsLeft() const;
  };
  extern const char INDEX_HTML[] PROGMEM;
  ```

- [ ] **Step 1: index_html.h schreiben**

`src/index_html.h` (die Seite entspricht dem abgenommenen Mockup `docs/design/Main.dc.html`):

```cpp
#pragma once
#include <pgmspace.h>

const char INDEX_HTML[] PROGMEM = R"rawliteral(<!doctype html>
<html lang="de"><head><meta charset="utf-8"><meta name="viewport" content="width=device-width,initial-scale=1"><title>Bodenfeuchte</title>
<style>
:root{--bg:#0d1116;--card:#141a21;--line:#242c36;--field:#0a0e13;--tx:#e6eaef;--mut:#8a94a1;--dim:#5b6572;--acc:#5eb1e8;--dry:#e8a85c;--wet:#9b8cf5}
*{box-sizing:border-box}
body{margin:0;background:var(--bg);color:var(--tx);font:15px/1.4 system-ui,-apple-system,"Segoe UI",sans-serif}
.wrap{max-width:480px;margin:0 auto;padding:20px 16px 28px;display:flex;flex-direction:column;gap:14px}
.mono{font-family:ui-monospace,"SF Mono",Menlo,Consolas,monospace;font-variant-numeric:tabular-nums}
.card{background:var(--card);border:1px solid var(--line);border-radius:12px;padding:18px 16px;display:flex;flex-direction:column;gap:14px}
h2{font-size:12px;font-weight:600;letter-spacing:.09em;text-transform:uppercase;color:var(--mut);margin:0}
label{display:block;font-size:13px;color:#b7c0ca;margin-bottom:6px}
input{width:100%;height:44px;background:var(--field);border:1px solid var(--line);border-radius:8px;padding:0 12px;font:inherit;color:var(--tx)}
input.mono{font-family:ui-monospace,"SF Mono",Menlo,Consolas,monospace}
input::placeholder{color:var(--dim)}
input:focus{outline:none;border-color:var(--acc)}
button{height:44px;border-radius:8px;padding:0 14px;font:inherit;font-size:14px;font-weight:600;white-space:nowrap;cursor:pointer;background:transparent;border:1px solid #2d3742;color:#cdd5de}
button.pri{background:var(--acc);border-color:var(--acc);color:#061018;height:48px;font-size:15px}
button.sm{height:36px;font-size:13px}
button:disabled{opacity:.5;cursor:default}
.row{display:flex;gap:8px}.row>*:first-child{flex:1;min-width:0}
.g2{display:grid;grid-template-columns:1fr 1fr;gap:10px}.g3{display:grid;grid-template-columns:2fr 1fr;gap:10px}
.hint{font-size:12px;color:var(--mut);margin:0;line-height:1.45}
.head{display:flex;justify-content:space-between;align-items:flex-start;gap:12px;padding:0 2px 6px}
.pill{display:flex;align-items:center;gap:8px;background:var(--card);border:1px solid var(--line);border-radius:999px;padding:6px 10px 6px 8px;font-size:12px;color:#b7c0ca;white-space:nowrap}
.dot{width:8px;height:8px;border-radius:50%;background:var(--acc);box-shadow:0 0 8px var(--acc)}
.big{font-size:64px;font-weight:600;line-height:1;letter-spacing:-.03em}
.badge{font-size:13px;font-weight:600;padding:5px 10px;border-radius:999px;border:1px solid var(--line)}
.bar{position:relative;height:10px;display:flex;gap:2px}.bar div{height:10px}
.z1{background:#3a2a17;border-radius:999px 0 0 999px}.z2{background:#172d3a}.z3{background:#221d3a;border-radius:0 999px 999px 0}
.mark{position:absolute;top:-4px;width:4px;height:18px;margin-left:-2px;border-radius:2px;left:0}
.scale{display:flex;justify-content:space-between;font-size:11px;color:var(--dim);margin-top:8px}
.msg{min-height:18px;font-size:13px;text-align:center;color:var(--mut)}
.msg.err{color:var(--dry)}.msg.ok{color:var(--acc)}
.unit{position:relative}.unit span{position:absolute;right:12px;top:12px;color:var(--dim);font-size:14px}
.ok{color:var(--acc)}
.tbox{display:flex;align-items:center;justify-content:space-between;gap:10px;background:var(--field);border:1px solid var(--line);border-radius:8px;padding:10px 12px}
.actions{display:flex;flex-direction:column;gap:10px;padding-top:6px}
</style></head><body><div class="wrap">

<div class="head">
 <div><div style="font-size:18px;font-weight:700">Bodenfeuchte</div><div class="mono" style="font-size:12px;color:var(--mut)" id="ids">&ndash;</div></div>
 <div class="pill"><span class="dot"></span>Konfigmodus <span class="mono" id="left" style="color:var(--tx)">&ndash;:&ndash;&ndash;</span></div>
</div>

<div class="card">
 <div style="display:flex;justify-content:space-between;align-items:flex-end;gap:12px">
  <div><h2>Aktuelle Feuchte</h2><div style="display:flex;align-items:baseline;gap:6px"><span class="mono big" id="pct">&ndash;</span><span class="mono" style="font-size:22px;color:var(--mut)">%</span></div></div>
  <div style="display:flex;flex-direction:column;align-items:flex-end;gap:8px;padding-bottom:4px"><span class="badge" id="lvl">&ndash;</span><span class="mono" style="font-size:12px;color:var(--mut)">Roh <span id="raw">&ndash;</span></span></div>
 </div>
 <div>
  <div class="bar"></div>
  <div class="mono scale"><span>0</span><span id="t1" style="color:var(--mut)">30 trocken</span><span id="t2" style="color:var(--mut)">70 nass</span><span>100</span></div>
 </div>
 <p class="hint">Aktualisiert alle 2 Sekunden. Prozent rechnet mit den unten eingetragenen Kalibrierwerten.</p>
</div>

<div class="card">
 <h2>Kalibrierung</h2>
 <div><label for="dryRaw">Rohwert trocken (Sensor an der Luft)</label><div class="row"><input class="mono" id="dryRaw" type="number" inputmode="numeric"><button type="button" onclick="cal('dryRaw')">Aktuellen Wert &uuml;bernehmen</button></div></div>
 <div><label for="wetRaw">Rohwert nass (Sensor im Wasser)</label><div class="row"><input class="mono" id="wetRaw" type="number" inputmode="numeric"><button type="button" onclick="cal('wetRaw')">Aktuellen Wert &uuml;bernehmen</button></div></div>
 <p class="hint">Sensor in Luft halten, Wert &uuml;bernehmen. Dann in ein Wasserglas, Wert &uuml;bernehmen.</p>
</div>

<div class="card">
 <h2>Bewertung und Intervall</h2>
 <div class="g2">
  <div><label for="dryBelowPct">Trocken unter</label><div class="unit"><input class="mono" id="dryBelowPct" type="number" min="0" max="100"><span>%</span></div></div>
  <div><label for="wetAbovePct">Nass ab</label><div class="unit"><input class="mono" id="wetAbovePct" type="number" min="0" max="100"><span>%</span></div></div>
 </div>
 <div><label for="intervalMin">Sendeintervall</label><div class="unit"><input class="mono" id="intervalMin" type="number" min="1" max="180"><span>Minuten</span></div></div>
 <p class="hint">Zwischen zwei Messungen schl&auml;ft der Sensor. K&uuml;rzere Intervalle kosten Akku.</p>
</div>

<div class="card">
 <div style="display:flex;justify-content:space-between;align-items:center"><h2>WLAN</h2><span class="mono" id="wifiState" style="font-size:12px">&ndash;</span></div>
 <div><label for="ssid">Netzwerk</label><div class="row"><input id="ssid" list="nets" autocomplete="off"><button type="button" id="scanBtn" onclick="scan()">Suchen</button></div><datalist id="nets"></datalist></div>
 <div><label for="wifiPassword">Passwort</label><input class="mono" id="wifiPassword" type="password" autocomplete="off"></div>
 <div class="g2">
  <div><label for="staticIp">Statische IP</label><input class="mono" id="staticIp" placeholder="leer = DHCP" inputmode="decimal"></div>
  <div><label for="gateway">Gateway</label><input class="mono" id="gateway" placeholder="192.168.1.1" inputmode="decimal"></div>
 </div>
 <div class="g2">
  <div><label for="subnet">Subnetzmaske</label><input class="mono" id="subnet" inputmode="decimal"></div>
  <div><label for="dns">DNS</label><input class="mono" id="dns" placeholder="leer = Gateway" inputmode="decimal"></div>
 </div>
 <p class="hint">Eine feste IP spart beim Aufwachen die DHCP-Zeit und damit Akku. Gateway und Maske sind dann Pflicht.</p>
</div>

<div class="card">
 <h2>MQTT</h2>
 <div class="g3">
  <div><label for="mqttHost">Broker</label><input class="mono" id="mqttHost"></div>
  <div><label for="mqttPort">Port</label><input class="mono" id="mqttPort" type="number" min="1" max="65535"></div>
 </div>
 <div class="g2">
  <div><label for="mqttUser">Benutzer</label><input id="mqttUser" placeholder="optional" autocomplete="off"></div>
  <div><label for="mqttPassword">Passwort</label><input class="mono" id="mqttPassword" type="password" placeholder="optional" autocomplete="off"></div>
 </div>
 <div class="g2">
  <div><label for="topicPrefix">Topic-Pr&auml;fix</label><input class="mono" id="topicPrefix"></div>
  <div><label for="deviceName">Ger&auml;tename</label><input class="mono" id="deviceName"></div>
 </div>
 <div class="tbox"><div><div style="font-size:12px;color:var(--mut)">Sendet nach</div><div class="mono" id="topic" style="font-size:13px">&ndash;</div></div><button type="button" class="sm" onclick="mqttTest()">Testnachricht</button></div>
</div>

<div class="actions">
 
 <button type="button" onclick="save()">Speichern</button>
 <button type="button" class="pri" onclick="saveSleep()">Speichern und Messbetrieb starten</button>
 <p class="hint" style="text-align:center">Danach misst der Sensor, sendet und schl&auml;ft bis zum n&auml;chsten Intervall. Zur&uuml;ck ins Men&uuml;: Taster am Geh&auml;use dr&uuml;cken.</p>
</div>

</div>
<script>
const $=id=>document.getElementById(id);
const F=['ssid','wifiPassword','staticIp','gateway','subnet','dns','mqttHost','mqttPort','mqttUser','mqttPassword','topicPrefix','deviceName','dryRaw','wetRaw','dryBelowPct','wetAbovePct','intervalMin'];
const NUM=['mqttPort','dryRaw','wetRaw','dryBelowPct','wetAbovePct','intervalMin'];
const NAMES={dry:'trocken',ok:'ok',wet:'nass'},COL={dry:'#e8a85c',ok:'#5eb1e8',wet:'#9b8cf5'};
let lastRaw=null,timer=null,ended=false;
function num(id){const v=parseInt($(id).value,10);return isNaN(v)?0:v}
function pctOf(raw){const d=num('dryRaw'),w=num('wetRaw');if(d===w)return 0;const p=Math.trunc((raw-d)*100/(w-d));return Math.max(0,Math.min(100,p))}
function levelOf(p){return p<num('dryBelowPct')?'dry':p>=num('wetAbovePct')?'wet':'ok'}
function render(){
 const d=num('dryBelowPct'),w=num('wetAbovePct');
 $('z1').style.flexBasis=d+'%';$('z2').style.flexBasis=Math.max(0,w-d)+'%';$('z3').style.flexBasis=Math.max(0,100-w)+'%';
 $('t1').textContent=d+' trocken';$('t2').textContent=w+' nass';
 $('topic').textContent=$('topicPrefix').value+'/'+$('deviceName').value+'/state';
 if(lastRaw===null)return;
 const p=pctOf(lastRaw),l=levelOf(p),c=COL[l];
 $('raw').textContent=lastRaw;$('pct').textContent=p;$('pct').style.color=c;$('pct').style.textShadow='0 0 24px '+c+'73';
 const b=$('lvl');b.textContent=NAMES[l];b.style.color=c;b.style.borderColor=c+'59';b.style.background=c+'1f';
 const m=$('mark');m.style.left=p+'%';m.style.background=c;m.style.boxShadow='0 0 10px '+c+'73';
}
function fmt(s){s=Math.max(0,s);return Math.floor(s/60)+':'+String(s%60).padStart(2,'0')}
async function poll(){
 if(ended)return;
 try{
  const r=await fetch('/api/status');const s=await r.json();
  lastRaw=s.raw;$('left').textContent=fmt(s.secondsLeft);
  $('ids').textContent=$('deviceName').value+' · '+s.apIp;
  const w=$('wifiState');w.textContent=s.staIp?'verbunden · '+s.staIp:'nicht verbunden';w.className='mono'+(s.staIp?' ok':'');
  render();
 }catch(e){say('Keine Verbindung zum Sensor','err')}
}
function collect(){const o={};for(const k of F)o[k]=NUM.includes(k)?num(k):$(k).value;return o}
async function loadCfg(){
 const r=await fetch('/api/config');const c=await r.json();
 for(const k of F)if(k in c)$(k).value=c[k];
 $('wifiPassword').placeholder=c.wifiPasswordSet?'•••••••• (unverändert)':'';
 $('mqttPassword').placeholder=c.mqttPasswordSet?'•••••••• (unverändert)':'optional';
 render();
}
function say(t,cls){const m=$('msg');m.textContent=t;m.className='msg '+(cls||'')}
async function post(url,body){
 const r=await fetch(url,{method:'POST',headers:{'Content-Type':'application/json'},body:JSON.stringify(body||{})});
 const t=await r.text();if(!r.ok)throw new Error(t||('HTTP '+r.status));return t;
}
async function save(){try{await post('/api/config',collect());$('wifiPassword').value='';$('mqttPassword').value='';await loadCfg();say('Gespeichert','ok')}catch(e){say(e.message,'err')}}
async function saveSleep(){
 try{await post('/api/config',collect());await post('/api/sleep');ended=true;clearInterval(timer);
  document.querySelectorAll('button').forEach(b=>b.disabled=true);
  say('Sensor misst, sendet und schläft. Zurück ins Menü mit dem Taster.','ok')}catch(e){say(e.message,'err')}
}
async function mqttTest(){try{await post('/api/config',collect());const t=await post('/api/mqtt-test');say(t||'Testnachricht gesendet','ok')}catch(e){say(e.message,'err')}}
async function scan(){
 const b=$('scanBtn');b.disabled=true;b.textContent='Suche…';
 try{const r=await fetch('/api/scan');const nets=await r.json();const dl=$('nets');dl.innerHTML='';
  for(const n of nets){const o=document.createElement('option');o.value=n.ssid;o.label=n.rssi+' dBm'+(n.secure?', gesichert':'');dl.appendChild(o)}
  say(nets.length+' Netzwerke gefunden, Feld Netzwerk antippen')}
 catch(e){say('Suche fehlgeschlagen','err')}
 b.disabled=false;b.textContent='Suchen';
}
function cal(id){if(lastRaw!==null){$(id).value=lastRaw;render()}}
document.querySelectorAll('input').forEach(i=>i.addEventListener('input',render));
loadCfg().then(poll);timer=setInterval(poll,2000);
</script></body></html>)rawliteral";
```

- [ ] **Step 2: web_ui.h schreiben**

`src/web_ui.h`:

```cpp
#pragma once
#include <ESP8266WebServer.h>
#include "config.h"

// Webserver des Konfigmodus. Bedient die Seite und die JSON-Schnittstelle.
// Jede Anfrage ausser /api/status setzt den Leerlauf-Timer zurueck.
class WebUi {
 public:
  WebUi(Config& cfg, unsigned long idleTimeoutMs);
  void begin();
  void handle();
  void setRaw(int raw);
  bool shouldExit() const;
  int secondsLeft() const;

 private:
  void touch();
  void handleRoot();
  void handleStatus();
  void handleGetConfig();
  void handlePostConfig();
  void handleScan();
  void handleMqttTest();
  void handleSleep();

  Config& cfg_;
  ESP8266WebServer server_;
  unsigned long idleTimeoutMs_;
  unsigned long lastRequestMs_;
  int raw_;
  bool sleepRequested_;
};
```

- [ ] **Step 3: web_ui.cpp schreiben**

`src/web_ui.cpp`:

```cpp
#include "web_ui.h"
#include <ESP8266WiFi.h>
#include "index_html.h"
#include "moisture.h"
#include "mqtt_payload.h"
#include "mqtt_sender.h"
#include "wifi_station.h"

static const char* JSON_TYPE = "application/json";
static const char* TEXT_TYPE = "text/plain; charset=utf-8";

WebUi::WebUi(Config& cfg, unsigned long idleTimeoutMs)
  : cfg_(cfg), server_(80), idleTimeoutMs_(idleTimeoutMs),
    lastRequestMs_(0), raw_(0), sleepRequested_(false) {}

void WebUi::begin() {
  lastRequestMs_ = millis();
  server_.on("/", HTTP_GET, [this] { handleRoot(); });
  server_.on("/api/status", HTTP_GET, [this] { handleStatus(); });
  server_.on("/api/config", HTTP_GET, [this] { handleGetConfig(); });
  server_.on("/api/config", HTTP_POST, [this] { handlePostConfig(); });
  server_.on("/api/scan", HTTP_GET, [this] { handleScan(); });
  server_.on("/api/mqtt-test", HTTP_POST, [this] { handleMqttTest(); });
  server_.on("/api/sleep", HTTP_POST, [this] { handleSleep(); });
  server_.onNotFound([this] { server_.send(404, TEXT_TYPE, "Nicht gefunden"); });
  server_.begin();
  Serial.println("Webserver auf Port 80 gestartet");
}

void WebUi::handle() { server_.handleClient(); }

void WebUi::setRaw(int raw) { raw_ = raw; }

bool WebUi::shouldExit() const {
  return sleepRequested_ || (millis() - lastRequestMs_) >= idleTimeoutMs_;
}

int WebUi::secondsLeft() const {
  unsigned long elapsed = millis() - lastRequestMs_;
  if (elapsed >= idleTimeoutMs_) return 0;
  return (int)((idleTimeoutMs_ - elapsed) / 1000UL);
}

void WebUi::touch() { lastRequestMs_ = millis(); }

void WebUi::handleRoot() {
  touch();
  server_.send_P(200, PSTR("text/html; charset=utf-8"), INDEX_HTML);
}

void WebUi::handleStatus() {
  // Absichtlich kein touch(): das Polling der Seite haelt den Konfigmodus nicht wach.
  String staIp = WiFi.status() == WL_CONNECTED ? WiFi.localIP().toString() : String();
  char buf[192];
  snprintf(buf, sizeof buf,
           "{\"raw\":%d,\"rssi\":%d,\"staIp\":\"%s\",\"apIp\":\"%s\",\"secondsLeft\":%d}",
           raw_, WiFi.status() == WL_CONNECTED ? WiFi.RSSI() : 0,
           staIp.c_str(), WiFi.softAPIP().toString().c_str(), secondsLeft());
  server_.send(200, JSON_TYPE, buf);
}

void WebUi::handleGetConfig() {
  touch();
  char buf[CONFIG_JSON_SIZE];
  if (serializeConfig(cfg_, buf, sizeof buf, true) == 0) {
    server_.send(500, TEXT_TYPE, "Konfiguration zu gross");
    return;
  }
  server_.send(200, JSON_TYPE, buf);
}

void WebUi::handlePostConfig() {
  touch();
  Config next = cfg_;
  if (!parseConfig(server_.arg("plain").c_str(), next)) {
    server_.send(400, TEXT_TYPE, "Ungueltiges JSON");
    return;
  }
  const char* problem = validateConfig(next);
  if (problem != nullptr) {
    server_.send(400, TEXT_TYPE, problem);
    return;
  }
  if (!saveConfig(next)) {
    server_.send(500, TEXT_TYPE, "Speichern fehlgeschlagen");
    return;
  }
  bool wifiChanged = strcmp(cfg_.ssid, next.ssid) != 0 ||
                     strcmp(cfg_.wifiPassword, next.wifiPassword) != 0 ||
                     strcmp(cfg_.staticIp, next.staticIp) != 0 ||
                     strcmp(cfg_.gateway, next.gateway) != 0 ||
                     strcmp(cfg_.subnet, next.subnet) != 0 ||
                     strcmp(cfg_.dns, next.dns) != 0;
  cfg_ = next;
  if (wifiChanged) {
    // Neue Zugangsdaten oder Adresse sofort probieren, nicht blockierend
    WiFi.disconnect();
    beginStation(cfg_);
  }
  Serial.println("Konfiguration gespeichert");
  server_.send(200, TEXT_TYPE, "ok");
}

void WebUi::handleScan() {
  touch();
  int n = WiFi.scanNetworks();
  if (n < 0) n = 0;
  // Nach Signalstaerke sortieren (kleine Liste, einfache Auswahl reicht)
  int idx[32];
  int count = n < 32 ? n : 32;
  for (int i = 0; i < count; i++) idx[i] = i;
  for (int i = 1; i < count; i++) {
    int k = idx[i], j = i - 1;
    while (j >= 0 && WiFi.RSSI(idx[j]) < WiFi.RSSI(k)) { idx[j + 1] = idx[j]; j--; }
    idx[j + 1] = k;
  }
  String out = "[";
  for (int i = 0; i < count; i++) {
    int id = idx[i];
    String ssid = WiFi.SSID(id);
    if (ssid.length() == 0) continue;
    ssid.replace("\\", "\\\\");
    ssid.replace("\"", "\\\"");
    if (out.length() > 1) out += ",";
    out += "{\"ssid\":\"" + ssid + "\",\"rssi\":" + String(WiFi.RSSI(id)) +
           ",\"secure\":" + (WiFi.encryptionType(id) == ENC_TYPE_NONE ? "false" : "true") + "}";
  }
  out += "]";
  WiFi.scanDelete();
  server_.send(200, JSON_TYPE, out);
}

void WebUi::handleMqttTest() {
  touch();
  if (WiFi.status() != WL_CONNECTED) {
    server_.send(502, TEXT_TYPE, "Kein WLAN, Testnachricht nicht moeglich");
    return;
  }
  if (cfg_.mqttHost[0] == '\0') {
    server_.send(400, TEXT_TYPE, "Kein MQTT-Broker eingetragen");
    return;
  }
  Reading r = evaluateReading(raw_, cfg_);
  char err[96];
  if (!mqttPublishReading(cfg_, r, WiFi.RSSI(), true, err, sizeof err)) {
    server_.send(502, TEXT_TYPE, err);
    return;
  }
  char topic[MQTT_TOPIC_SIZE];
  snprintf(topic, sizeof topic, "Testnachricht gesendet an %s/%s/state", cfg_.topicPrefix, cfg_.deviceName);
  server_.send(200, TEXT_TYPE, topic);
}

void WebUi::handleSleep() {
  touch();
  server_.send(200, TEXT_TYPE, "ok");
  sleepRequested_ = true;
}
```

- [ ] **Step 4: Build prüfen**

```bash
pio run -e esp12e
```

Erwartet: `SUCCESS`. Der Raw-String-Literal ist etwa 9 KB; falls der Compiler über Länge klagt, die Seite in zwei Literale aufteilen, die per Präprozessor aneinandergehängt werden (`"..." "..."`).

Bekannte Stolperstellen:
- `ENC_TYPE_NONE` braucht `#include <ESP8266WiFi.h>` (ist oben eingebunden).
- `strcmp` braucht `<string.h>` (kommt über Arduino.h).

- [ ] **Step 5: Commit**

```bash
git add src/index_html.h src/web_ui.h src/web_ui.cpp
git commit -m "feat: Web-Oberflaeche und JSON-Schnittstelle des Konfigmodus"
```

---

### Task 7: Startablauf, Messzyklus und Deep Sleep

**Files:**
- Modify: `src/main.cpp` (komplett ersetzen)
- Modify: `platformio.ini` (WiFiManager entfernen)

**Interfaces:**
- Consumes: alles aus Task 1 bis 6.
- Produces: lauffähige Firmware.

- [ ] **Step 1: WiFiManager aus platformio.ini entfernen**

In `[env:esp12e]` die Zeile `  tzapu/WiFiManager` löschen. Ergebnis:

```ini
lib_deps =
  bblanchon/ArduinoJson@^7
  knolleary/PubSubClient@^2.8
```

- [ ] **Step 2: main.cpp ersetzen**

`src/main.cpp`:

```cpp
#include <Arduino.h>
#include <ESP8266WiFi.h>
#include <LittleFS.h>
extern "C" {
#include <user_interface.h>
}
#include "config.h"
#include "moisture.h"
#include "boot_mode.h"
#include "mqtt_sender.h"
#include "wifi_station.h"
#include "web_ui.h"

static const char* AP_NAME     = "SoilMoisture-Setup";
static const char* AP_PASSWORD = "bodenfeuchte";

static const unsigned long WIFI_TIMEOUT_MS   = 15000;
static const unsigned long CONFIG_TIMEOUT_MS = 5UL * 60UL * 1000UL;
static const unsigned long MEASURE_PERIOD_MS = 2000;
static const int SAMPLES = 10;   // Anzahl Messungen, die gemittelt werden

static Config cfg;

int readMoistureRaw() {
  long sum = 0;
  for (int i = 0; i < SAMPLES; i++) {
    sum += analogRead(A0);
    delay(10);
  }
  return sum / SAMPLES;
}

// Verbindet mit dem gespeicherten WLAN, blockiert hoechstens timeoutMs.
static bool connectStation(unsigned long timeoutMs) {
  if (!beginStation(cfg)) return false;
  Serial.printf("Verbinde mit '%s'", cfg.ssid);
  unsigned long start = millis();
  while (WiFi.status() != WL_CONNECTED && millis() - start < timeoutMs) {
    delay(100);
    Serial.print('.');
  }
  Serial.println();
  if (WiFi.status() != WL_CONNECTED) return false;
  Serial.printf("Verbunden, IP %s, RSSI %d\n", WiFi.localIP().toString().c_str(), WiFi.RSSI());
  return true;
}

// Kehrt nicht zurueck. Wakeup ueber GPIO16 -> RST.
static void goToSleep() {
  uint64_t us = (uint64_t)cfg.intervalMin * 60ULL * 1000000ULL;
  Serial.printf("Deep Sleep fuer %d Minuten (wach seit %lu ms)\n", cfg.intervalMin, millis());
  Serial.flush();
  WiFi.mode(WIFI_OFF);
  ESP.deepSleep(us);
  delay(500);   // deepSleep braucht einen Moment
}

// Messen, senden, schlafen. Jeder Fehler fuehrt trotzdem zum Schlafen.
static void measureCycle() {
  Reading r = evaluateReading(readMoistureRaw(), cfg);
  Serial.printf("Roh: %4d  Feuchte: %3d %%  %s\n", r.raw, r.percent, levelNameDe(r.level));

  if (!configIsValid(cfg)) {
    Serial.println("Keine gueltige Konfiguration, nichts zu senden");
    goToSleep();
  }
  WiFi.mode(WIFI_STA);
  if (!connectStation(WIFI_TIMEOUT_MS)) {
    Serial.println("WLAN nicht erreichbar");
    goToSleep();
  }
  char err[96];
  if (!mqttPublishReading(cfg, r, WiFi.RSSI(), false, err, sizeof err)) {
    Serial.println(err);
  } else {
    Serial.println("Gesendet");
  }
  goToSleep();
}

// Access Point plus Heimnetz, Webserver, bis Timeout oder /api/sleep.
static void runConfigMode() {
  WiFi.mode(WIFI_AP_STA);
  WiFi.softAP(AP_NAME, AP_PASSWORD);
  beginStation(cfg);   // nicht blockierend, Erfolg egal
  Serial.printf("Konfigmodus: AP '%s', Passwort '%s', http://%s/\n",
                AP_NAME, AP_PASSWORD, WiFi.softAPIP().toString().c_str());

  WebUi ui(cfg, CONFIG_TIMEOUT_MS);
  ui.begin();

  unsigned long lastMeasure = 0;
  bool reportedSta = false;
  while (!ui.shouldExit()) {
    ui.handle();
    if (millis() - lastMeasure >= MEASURE_PERIOD_MS) {
      lastMeasure = millis();
      ui.setRaw(readMoistureRaw());
    }
    if (!reportedSta && WiFi.status() == WL_CONNECTED) {
      reportedSta = true;
      Serial.printf("Auch im Heimnetz erreichbar: http://%s/\n", WiFi.localIP().toString().c_str());
    }
    delay(2);
  }
  Serial.println("Konfigmodus beendet, wechsle in den Messbetrieb");
  WiFi.softAPdisconnect(true);
  measureCycle();
}

void setup() {
  Serial.begin(115200);
  Serial.println();
  WiFi.persistent(false);   // Zugangsdaten nur aus config.json, kein Flash-Schreiben durch den Core

  if (!LittleFS.begin()) {
    Serial.println("LittleFS konnte nicht gemountet werden");
  }
  cfg = defaultConfig();
  loadConfig(cfg);

  uint32_t reason = ESP.getResetInfoPtr()->reason;
  BootMode mode = chooseBootMode(reason, configIsValid(cfg));
  Serial.printf("Reset-Grund %u, Konfiguration %s, Modus %s\n",
                reason, configIsValid(cfg) ? "gueltig" : "unvollstaendig", bootModeName(mode));

  if (mode == BootMode::Configure) {
    runConfigMode();
  } else {
    measureCycle();
  }
}

void loop() {
  // Alles passiert in setup(); measureCycle() endet immer im Deep Sleep.
}
```

- [ ] **Step 3: Build prüfen**

```bash
pio run -e esp12e
```

Erwartet: `SUCCESS`. Auf RAM/Flash-Ausgabe achten: RAM sollte unter 60 % liegen.

- [ ] **Step 4: Native Tests laufen weiterhin**

```bash
pio test -e native
```

Erwartet: alle vier Gruppen `PASSED`.

- [ ] **Step 5: Flashen und Gerätetest**

Vor dem Flashen die Brücke GPIO16 zu RST trennen, falls der Upload nicht anläuft.

```bash
pio run -e esp12e -t upload
pio device monitor
```

Testablauf am seriellen Monitor (jeden Punkt abhaken):

1. Erster Start ohne `config.json`: Ausgabe `Keine config.json, Standardwerte`, `Modus Konfigmodus`, `AP 'SoilMoisture-Setup'`.
2. Mit dem Handy ins WLAN `SoilMoisture-Setup` (Passwort `bodenfeuchte`), `http://192.168.4.1/` öffnen. Seite lädt, Prozent aktualisiert sich, Restzeit zählt herunter.
3. "Suchen" listet Netzwerke. Heimnetz und Passwort eintragen, Broker eintragen, "Speichern". Meldung `Gespeichert`. Serieller Monitor: `Konfiguration gespeichert`, danach `Auch im Heimnetz erreichbar: http://...`.
4. Seite über die Heimnetz-IP öffnen. WLAN-Karte zeigt `verbunden · IP`.
5. Sensor in Luft, "Aktuellen Wert übernehmen" bei trocken. Sensor ins Wasserglas, bei nass übernehmen. Prozentanzeige springt entsprechend.
6. "Testnachricht": am Broker mit `mosquitto_sub -h <broker> -t 'soil/#' -v` erscheint `soil/sensor1/state {"raw":..,"percent":..,"level":"..","rssi":..,"test":true}`.
7. "Speichern und Messbetrieb starten": Monitor zeigt Messung, `Gesendet`, `Deep Sleep fuer 15 Minuten`. Am Broker kommt die Nachricht ohne `test` an.
8. Brücke GPIO16 an RST setzen. Intervall zum Testen auf 1 Minute stellen (über Konfigmodus, Taster). Nach einer Minute: Monitor zeigt `Reset-Grund 5`, `Modus Messbetrieb`, Nachricht am Broker, wieder Deep Sleep. Wachzeit laut Ausgabe `wach seit` unter 10000 ms.
9. Taster am RST drücken: `Reset-Grund 6`, `Modus Konfigmodus`.
10. Seite schließen, 5 Minuten warten: Monitor zeigt `Konfigmodus beendet`, Messzyklus, Deep Sleep.
11. Falschen Broker eintragen, Messbetrieb starten: Monitor zeigt `MQTT-Verbindung ... fehlgeschlagen`, danach trotzdem Deep Sleep.
12. Statische IP: freie Adresse im Heimnetz, Gateway und Maske eintragen, "Speichern". Monitor zeigt `Statische IP ...`, WLAN-Karte zeigt nach kurzer Zeit `verbunden · <diese IP>`. Seite über die neue IP öffnen. Messbetrieb starten: Wachzeit laut `wach seit` ist kürzer als mit DHCP.
13. Statische IP ohne Gateway speichern: Meldung `Gateway fehlt oder ist keine gueltige IPv4-Adresse`, nichts gespeichert. Feld leeren, speichern: wieder DHCP.

Probleme dokumentieren und beheben, bevor der Commit passiert. Wenn ein Punkt nicht geht, ist das ein Fehler in diesem Task und nicht "später".

- [ ] **Step 6: Commit**

```bash
git add platformio.ini src/main.cpp
git commit -m "feat: Startablauf mit Reset-Grund, Messzyklus mit Deep Sleep, Konfigmodus"
```

---

### Task 8: README

**Files:**
- Create: `README.md`

- [ ] **Step 1: README schreiben**

`README.md`:

```markdown
# SoilMoistureSens

Batteriebetriebener Bodenfeuchtesensor auf ESP-12E (ESP8266) mit Solarladung.
Misst alle 15 Minuten, sendet per MQTT und schläft dazwischen im Deep Sleep.
Einstellungen laufen über eine Web-Oberfläche auf dem Chip.

## Hardware

- ESP-12E, analoger Feuchtesensor an A0
- 18650-Akku mit HW-775-Lademodul, 14,5 cm Solarpanel (Gehäuse unter `case/`)
- **Brücke GPIO16 an RST**: ohne sie wacht der Chip nicht aus dem Deep Sleep auf
- **Taster zwischen RST und GND** am Gehäuse: öffnet den Konfigmodus

## Flashen

```bash
pio run -e esp12e -t upload
pio device monitor
```

Startet der Upload nicht, die Brücke GPIO16 zu RST für den Upload trennen.

## Bedienung

**Konfigmodus** startet beim ersten Einschalten (ohne Konfiguration) oder nach
Druck auf den Taster.

1. Mit WLAN `SoilMoisture-Setup` verbinden, Passwort `bodenfeuchte`.
2. `http://192.168.4.1/` öffnen.
3. WLAN, MQTT-Broker, Kalibrierung und Intervall eintragen.
4. "Speichern und Messbetrieb starten".

Sobald das Heimnetz eingetragen ist, ist die Seite auch über die dort
vergebene IP erreichbar (steht im seriellen Monitor und in der WLAN-Karte).

Kalibrieren: Sensor an der Luft halten und bei "trocken" den aktuellen Wert
übernehmen, dann ins Wasserglas und bei "nass" übernehmen.

Statische IP: Wer eine feste Adresse einträgt, spart beim Aufwachen die
DHCP-Zeit. Gateway und Subnetzmaske sind dann Pflicht, DNS ist optional
(leer = Gateway). Feld leer lassen bedeutet DHCP.

Der Konfigmodus endet nach 5 Minuten ohne Bedienung von selbst.

**Messbetrieb**: aufwachen, messen, senden, schlafen. Ziel unter 10 Sekunden
wach. Ohne WLAN oder Broker schläft der Sensor trotzdem bis zum nächsten
Intervall, damit der Akku geschont wird.

## MQTT

Topic `<Präfix>/<Gerätename>/state`, retained:

```json
{"raw":202,"percent":54,"level":"ok","rssi":-61}
```

`level` ist `dry`, `ok` oder `wet` nach den eingestellten Schwellen.

## Entwicklung

```bash
pio test -e native      # Logik-Tests auf dem PC (braucht g++)
pio run -e esp12e       # Firmware bauen
```

Konfiguration liegt in `/config.json` im LittleFS des Chips. Zum Zurücksetzen
`pio run -e esp12e -t erase` und neu flashen.

Design-Spec: `docs/superpowers/specs/2026-09-12-config-ui-and-sleep-mode-design.md`
Mockup der Oberfläche: `docs/design/Main.dc.html`
```

- [ ] **Step 2: Commit**

```bash
git add README.md
git commit -m "docs: README mit Hardware, Flashen und Bedienung"
```

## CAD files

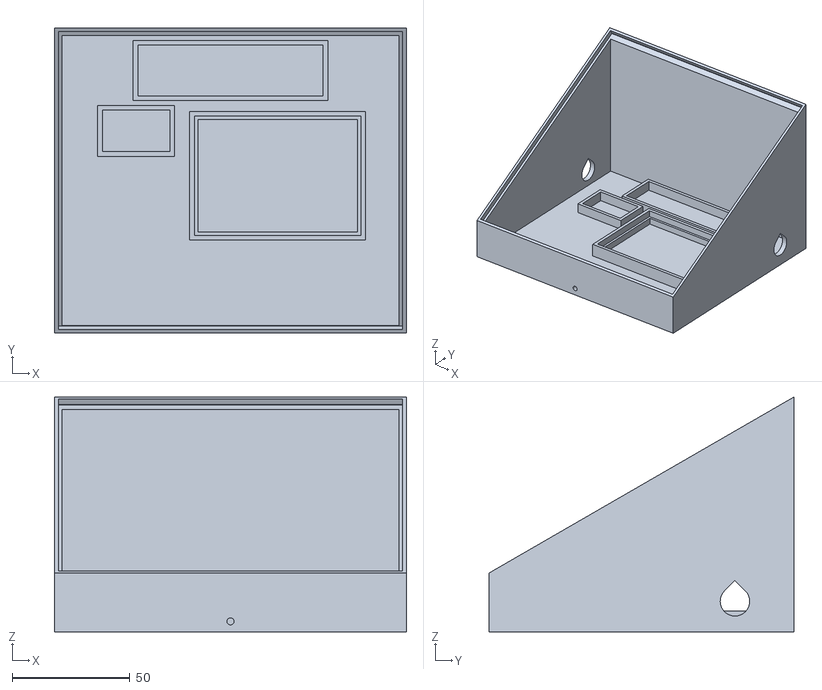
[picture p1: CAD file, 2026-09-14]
case/solar_station_case.stl
149.2 x 129.2 x 99.6

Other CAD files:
case/solar_station_case.blend

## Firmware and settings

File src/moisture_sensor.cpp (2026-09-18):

#include "moisture_sensor.h"

#include <Arduino.h>
#include <Wire.h>
#include <ADS1X15.h>

#include "moisture.h"

static const uint8_t SENSOR_PWR_PIN = 14;          // D5 -> Gate Q1, R1 10k nach GND
static const uint8_t ADS_ADDRESS = 0x48;           // ADDR an GND
static const uint8_t ADS_CHANNEL = 0;              // Sensor AOUT an A0
static const unsigned long SENSOR_SETTLE_MS = 200; // Einschwingzeit des Sensors nach Power-on
static const int SAMPLES = 10;                     // Anzahl Wandlungen, die gemittelt werden

static ADS1115 ads(ADS_ADDRESS);
static bool adsReady = false;
static bool powered = false;

bool moistureSensorBegin() {
  pinMode(SENSOR_PWR_PIN, OUTPUT);
  digitalWrite(SENSOR_PWR_PIN, LOW);
  powered = false;

  Wire.begin();   // SDA GPIO4 (D2), SCL GPIO5 (D1)
  adsReady = ads.begin() && ads.isConnected();
  if (adsReady) {
    ads.setGain(1);       // +-4,096 V, 0,125 mV pro Schritt; Sensor (an 5 V) liefert 1,2..3 V
    ads.setMode(1);       // Single-Shot: schlaeft zwischen den Wandlungen
    ads.setDataRate(4);   // 128 SPS, rund 8 ms pro Wandlung
  }
  return adsReady;
}

void moistureSensorPower(bool on) {
  if (on == powered) return;
  digitalWrite(SENSOR_PWR_PIN, on ? HIGH : LOW);
  powered = on;
  if (on) delay(SENSOR_SETTLE_MS);
}

int moistureSensorRead() {
  if (!adsReady || !powered) return RAW_INVALID;
  long sum = 0;
  for (int i = 0; i < SAMPLES; i++) {
    int16_t v = ads.readADC(ADS_CHANNEL);
    if (ads.getError() != ADS1X15_OK) return RAW_INVALID;
    if (v < 0) v = 0;   // leichtes Rauschen um 0 V nicht negativ werden lassen
    sum += v;
    delay(10);
  }
  return (int)(sum / SAMPLES);
}

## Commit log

2026-09-14 feat: Konfigurationsstruktur mit JSON-Konvertierung, Validierung und IPv4-Parser
    Claude-Session: https://claude.ai/code/session_01NkZXyDR7k2FayFFu2Spg1a
2026-09-14 feat: MQTT-Topic und Payload als testbare Funktionen
    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
2026-09-14 feat: Web-Oberflaeche und JSON-Schnittstelle des Konfigmodus
    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
2026-09-14 feat: Startablauf mit Reset-Grund, Messzyklus mit Deep Sleep, Konfigmodus
    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
    [main.cpp]
2026-09-14 fix: Deep-Sleep-Dauer auf ESP.deepSleepMax() begrenzen
    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
    [main.cpp]
2026-09-14 docs: README mit Hardware, Flashen und Bedienung
    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
2026-09-14 fix: config.json atomar schreiben, statische JSON-Puffer
    saveConfig schreibt jetzt zuerst nach /config.json.tmp und ersetzt
    /config.json erst per rename, wenn der Schreibvorgang vollstaendig war.
    So bleibt bei LittleFS-Schreibfehler oder Stromausfall waehrend des
    Schreibens die alte Datei erhalten (F1).
    Die 1-KB-JSON-Puffer in loadConfig, saveConfig und
    WebUi::handleGetConfig sind jetzt static: 1 KB gehoert nicht auf den
    4-KB-Stack des ESP8266, der Code ist single-threaded (F4).
    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
    [config.cpp]
2026-09-14 fix: WLAN erst nach HTTP-Antwort neu verbinden
    handlePostConfig trennte bei geaenderten WLAN-Daten die Verbindung
    (WiFi.disconnect/beginStation) VOR server_.send(200). Kam die Anfrage
    ueber die Heimnetz-IP, starb die TCP-Verbindung vor der Antwort und der
    Browser sah einen Fehler.
    Jetzt wird zuerst geantwortet; die Rekonfiguration passiert 500 ms
    spaeter in WebUi::handle() ueber ein Pending-Flag, analog zum
    bestehenden Sleep-Muster.
    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
2026-09-14 fix: statische IP strenger pruefen, WiFi.config-Ergebnis auswerten
    wifi_station.cpp: Rueckgabewert von WiFi.config() wird jetzt geprueft
    und bei Ablehnung seriell gemeldet; die Verbindung faellt dann auf DHCP
    zurueck statt eine unwirksame statische IP anzunehmen (F3 Teil A).
    config.cpp/validateConfig: Der ESP8266-Core liest WiFi.config()-Argumente
    nur bei einer gueltigen Maske (erstes Oktett 255, zusammenhaengende
    Einsen) in der erwarteten Reihenfolge und lehnt IP/Gateway in
    verschiedenen Subnetzen ab. validateConfig prueft das jetzt zusaetzlich
    zur bisherigen Parsbarkeitspruefung (F3 Teil B). Dafuer zwei
    Arduino-freie Helfer ipv4ToU32/isValidNetmask in ipv4.h.
    Tests: test_valid_netmask (i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
    [config.cpp]
2026-09-14 fix: leere Zahlenfelder nicht als 0 speichern
    collect() schickte fuer ein leeres Zahlenfeld bisher 0 mit, weil num()
    NaN auf 0 abbildet. Jetzt wird ein leeres Zahlenfeld beim Absenden
    uebersprungen; parseConfig behaelt dann den gespeicherten Wert, und
    loadCfg() fuellt das Feld nach dem Speichern wieder. num() fuer die
    Live-Berechnung der Anzeige bleibt unveraendert.
    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
2026-09-14 refactor: main.cpp Kleinigkeiten (noreturn goToSleep, sofortiger Rohwert)
    goToSleep() ist jetzt als [[noreturn]] markiert; nach ESP.deepSleep()
    haengt eine Endlosschleife statt eines einzelnen delay(500), damit der
    Compiler die Annotation nicht als falsch ansieht.
    runConfigMode() setzt den Rohwert direkt nach ui.begin() einmal per
    readMoistureRaw(), damit die Seite beim Laden nicht bis zu 2 s lang
    Roh 0 anzeigt.
    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
2026-09-14 test: Round-Trip mit Passwoertern, Maximalgroesse, Topic-Laenge
    Zusaetzliche native Testfaelle aus der Gesamtpruefung, unabhaengig von
    den F1-F5-Fixes:
    - test_masked_roundtrip_keeps_passwords: serializeConfig(mask=true)
    gefolgt von parseConfig in dieselbe Config veraendert Passwoerter und
    uebrige Felder nicht.
    - test_full_config_fits_buffer: alle Strings auf Maximallaenge gefuellt,
    serializeConfig passt maskiert wie unmaskiert in CONFIG_JSON_SIZE.
    - test_topic_max_length: 32-Zeichen-Praefix und -Geraetename ergeben ein
    71 Zeichen langes Topic, das in MQTT_TOPIC_SIZE passt.
    Claude-Session: https://claude.ai/code/session_01NkZX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
2026-09-14 docs: Spec um strengere IP-Pruefung, atomares Speichern und verzoegerten WLAN-Reconnect ergaenzt
    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
2026-09-14 chore: Ausgangsstand mit WiFiManager-Setup, Gehäuse, Design-Spec und Plan
    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
    [solar_station_case.blend, solar_station_case.stl]
2026-09-18 feat: Feuchte ueber ADS1115 mit geschalteter Sensorversorgung, Konfigmodus per Doppel-Reset
    Der Sensor wird ueber GPIO14 und einen MOSFET nur fuer die Messung
    eingeschaltet, gemessen wird am ADS1115 (0x48, A0, Gain 1). Der
    Konfigmodus startet durch zweimal RST innerhalb von 3 s, der Merker
    liegt im RTC-Speicher. Ein eigener Taster entfaellt.
    [main.cpp, moisture_sensor.cpp]
2026-09-18 docs: Schaltplan Rev D, Hardware-Abschnitt und Stueckliste in der README
    Der ESP haengt ueber einen HT7333 am Akku und wird am 3V3-Pin gespeist.
    Der v1.2-Sensor braucht 5 V, die liefert ein MT3608 direkt an VBAT; der
    Sensor-MOSFET schaltet die Masse von Step-up und Sensor gemeinsam.
    Schaltplan als HTML-Quelle und zwei SVG-Blaetter unter docs/hardware.
2026-09-18 fix: Review-Befunde (Kalibrier-Defaults, atomares Speichern, MQTT-Test, DHCP-Reset)
    - Kalibrier-Defaults auf ADS1115-Skala (24000/9600), Tests, Spec und README angepasst
    - saveConfig ohne remove vor rename: lfs_rename ersetzt das Ziel atomar
    - MQTT-Test wartet auf die WLAN-Neuverbindung (POST /api/config antwortet 'reconnect')
    - MQTT-Test sendet keinen ungueltigen Rohwert als retained state
    - nach abgelehnter statischer IP explizit zurueck auf DHCP
    - Hinweise in der Oberflaeche nennen den Doppel-Reset statt eines Tasters
    [config.cpp]
